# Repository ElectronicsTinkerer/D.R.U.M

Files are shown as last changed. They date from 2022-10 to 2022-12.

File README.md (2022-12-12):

# D.R.U.M (Digital Rhythmic Utility Modules)
Files for the D.R.U.M. Machine, the modular, expandable drum machine complete with digital AND analog circuitry!

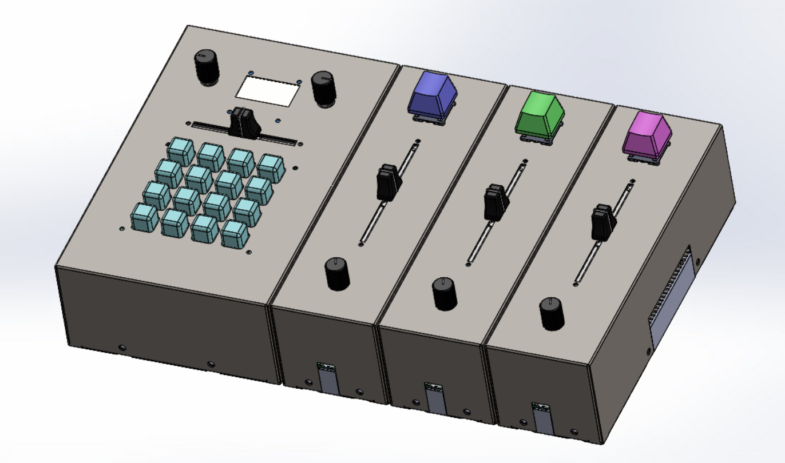
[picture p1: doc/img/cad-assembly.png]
CAD rendering of the DRUM sequencer with three modules attached to its right size

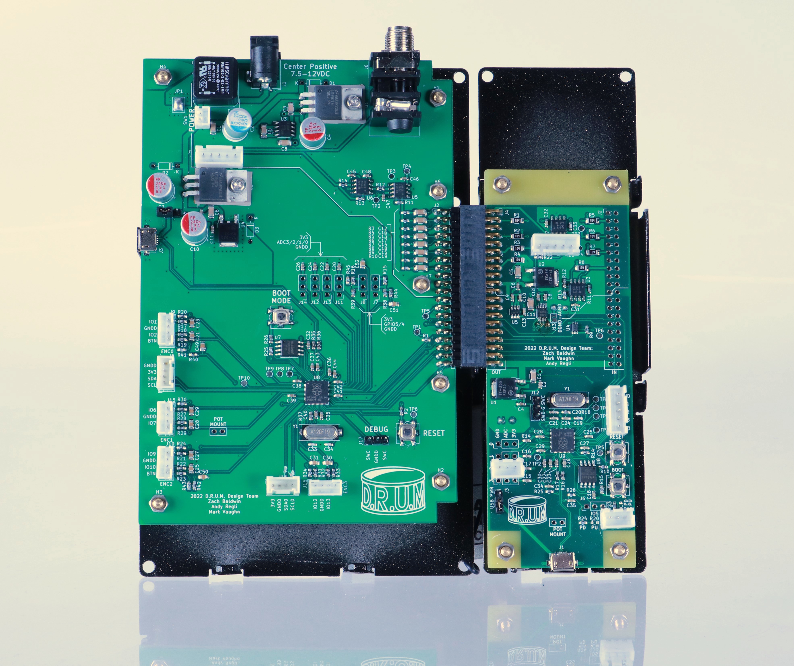
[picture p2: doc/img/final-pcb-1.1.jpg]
Assembled PCBs, mounted to the bottom of the housing

Fully assembled device

## File Structure

```
.
├── doc             # Documentation on components, thoughts, h/sware details
├── module          # Files specific to the modules
│   ├── cad         # Housing design
│   ├── hardware    # PCB design (kicad)
│   └── software    # Module firmware
├── README.md       # INFO (this doc)
├── samples         # Sample to c-array conversion utils
│   └── bass-0      # Revision 0 Bass Drum samples (RAW, PCM-16)
├── sequencer       # Files specific to the sequencer
│   ├── cad         # Housing design
│   ├── hardware    # PCB design (kicad)
│   └── software    # Sequencer firmware
└── slidepot        # Slide potentiometer daughter board
    ├── cad         # 3D models for slidepot (knob)
    └── hardware    # Daughter board design
```

## System Architecture

The D.R.U.M. system is composed of a sequencer (the base and primary controller) and between 1 and 8 "modules." The digital section of each device is based on the RP2040 microcontroller, the same device found on the Raspberry Pi Pico development board. The RP2040 was selected due to its relatively high clock speed (compared to a '328, for example), multiple cores, its PIO state machines, good documentation, and great SDK. (Oh, and it's only $1). 

The **analog section** is designed around a completely passive routing scheme, where each of the channels is simply shifted one position over each module. This allows for up to 8 modules to be connected in series before a summing module is necessary to combine the channels. Each module has a 100k pull down resistor on the lines to ensure that they are not floating. The eight lines enter the sequencer for final summation and are dc isolated via separate capacitors for each line. Although currently unused, each module also has a comparator circuit on channel 8 to detect when all the channels have been filled to signal to the RP2040 onboard that the max channel count has been reached. Each module is in charge of the amplitude that it outputs; that is, the mixing between each module is performed on a per-module basis.

The **digital section** is designed around the RP2040 microcontroller. All the modules communicate over a 32-bit SPI-like scan chain which is controlled by the sequencer. The scan chain is further documented below. The modules have the ability to send an interrupt to the sequencer when they have been "(un)selected" by the user. Only one device can be "selected" at a time. Being selected means that that module's data will be copied to the sequencer and displayed on the UI. Deselection of the module hides this information from the user but retains it within the module's memory, allowing multiple modules to have different user data. Tempo synchronization between the modules is accomplished by an interrupt line which is driven by the sequencer. This outputs a periodic pulse each "tick" (currently each beat, but in the future when microbeats are implemented, this will pulse each microbeat). The length of the tick tells the module if the beat is the start of a new measure. A short pulse (<75us) is beat 0 while a long pulse (>75us) is any other beat.

The overall routing of signals is approximated by the following diagram:

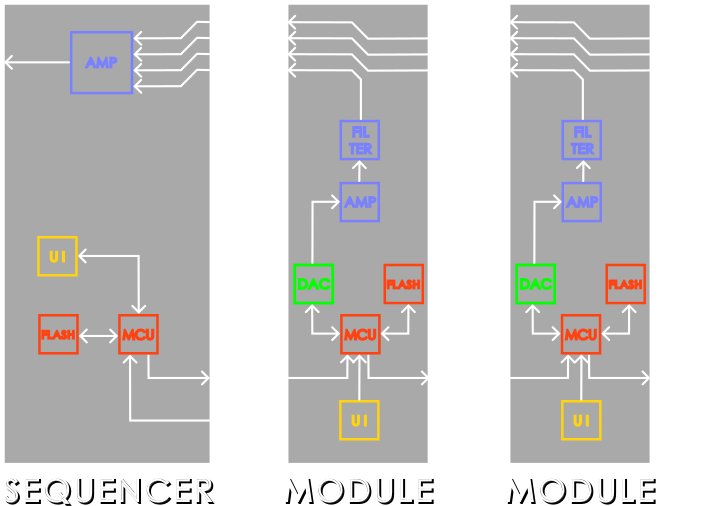
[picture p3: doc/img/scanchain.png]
System architecture block diagram


## Docs

The `doc` directory contains most of the relevant documentation to this project. This will contain information about different parts of the system, such as the serial bus protocol or the data sheets for the components used.

* [`serbus.md`](doc/serbus.md) contains information on the custom 32-bit scan chain protocol used for communication between modules. This is implemented using the RP2040's PIO state machines, meaning that the bus can be much faster than bit-banging in software. It also allows an "address-free" control scheme, where modules (bus devices) are selected by their depth on the scan chain, rather than an address. This allows a user to completely fill the bus with 8 of the same module if desired.
* [`ipc.md`](doc/ipc.md) contains information on how information is sent between the different processes running on the sequencer and the module. Both CPU cores on the RP2040 are utilized in each design to allow simultaneous execution of multiple tasks. In the case of the sequencer, the I2C bus is rather slow compared to the amount of data to be sent over it, so the second thread (core 1) handles data modification and transfer to/from the modules.
* [`samples.md`](doc/samples.md) contains information on the used sample format and how playback is achieved as well as how the signed to unsigned conversion is performed.

## Usage

### Power Up / Reset

Upon power up, the sequencer will run through an auto detection routine to determine how many modules are connected. It also will cycle all neo pixels in the 4x4 grid pad white to visually test that all LEDs and their individual colors are functioning properly. After this initialization sequence is performed, the sequencer will display its default config on the OLED screen.

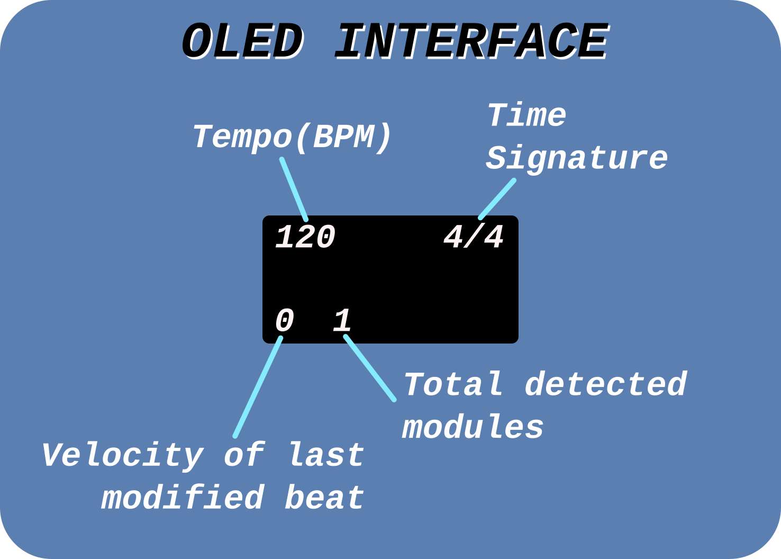
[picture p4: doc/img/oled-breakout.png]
OLED interface diagram; Tempo in upper left, time signature in upper right, last modified velocity in lower left, detected module count


### Programming a Beat

To start programming in a beat, the user must first select the module that they would like to program. Modules should have a button on board along with a visual indicator which can be used to select/deselect a module and identify if a module is selected. When a module is selected, the current contents of the sequencer's beat grid are saved to the previously selected module and the newly selected module's saved beat data is loaded into the grid.

Each square on the grid represents a sixteenth note (1/16) at the current tempo marking (although this may be changed in future revisions). Additionally, each square can have up to 7 different values associated with it. These values are called the *velocity* of that note. In addition to the 7 different velocities, a square can be off, giving 8 total possible states. The state of all the squares is indicated by the color of that square. Additionally, each time that a square is pressed, its new velocity value is displayed on the OLED screen to give quantitative feedback on any changes. Beats can be programmed while the sequencer is in active playback or while the system is in a stopped state.

### Playback

Playback is controlled by the tempo knob. This knob controls the tempo by rotating it; clockwise increases the tempo by one beat per minute per click of the knob and counter-clockwise decreases the tempo. Pressing the know will switch the sequencer between active playback, *sequencing*, and stopped, *idle*, states. During playback, the current square will light up white to indicate the location of the beat. This light will extinguish during the idle state.

The time signature of the playback can be changed via the time signature knob. This cycles through all built-in time signatures in a circular manner. Beats which are not available in a given time signature will be "grayed out" with a dim white square. Note that beats which had been programmed before changing the time signature but are not available in a new time signature will retain their original values but will not be played back. Holding down the time signature knob for about one second will clear the current pattern on the grid.

### Interface

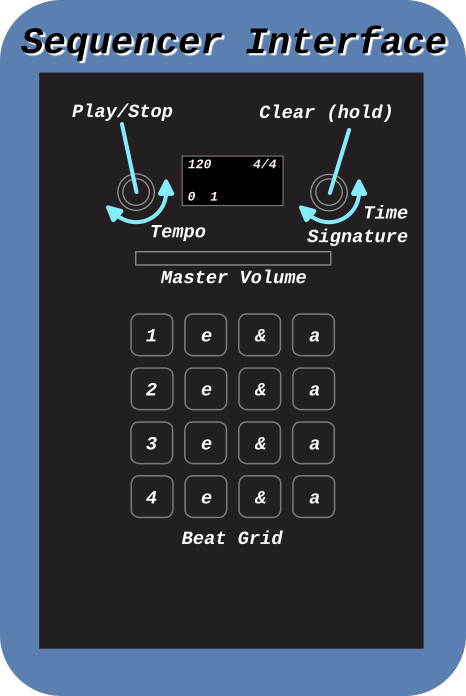
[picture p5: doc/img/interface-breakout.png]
Interface breakout of the sequencer


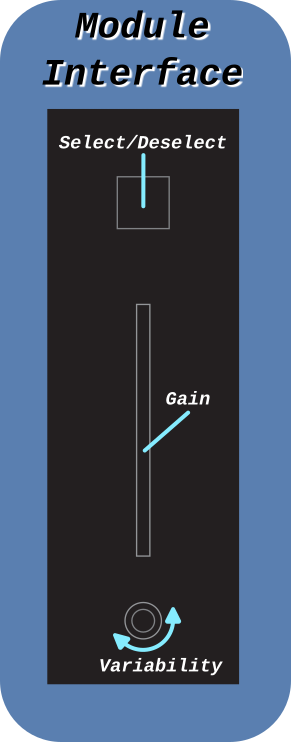
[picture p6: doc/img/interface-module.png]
Interface breakout of the bass module


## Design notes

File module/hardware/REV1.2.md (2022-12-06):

# Things to fix in module HW REV 1.2

* Incorrect GPIO numbering in silk for button inputs
* Incorrect GPIO numbering for encoder inputs

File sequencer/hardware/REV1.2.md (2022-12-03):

# Things to fix in REV 1.2

* Incorrect pinout of 40-pin header
* I2C0 needs to be common between OLED and button pad
* Rotate button footprint
* Update USB micro connector footprints (the pegs don't have holes)
* Fix silk error on debug header (incorrect pin labels)
* Move output level pot header to right side of board (near output jack)

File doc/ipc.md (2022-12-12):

# Inter-Process Communication

Communication between the processes approximately follows the following flow diagram. Note that the PIO state machines are excluded from the diagram. They are implicitly contained "within" core 1 to allow the cores to use the scan chain.

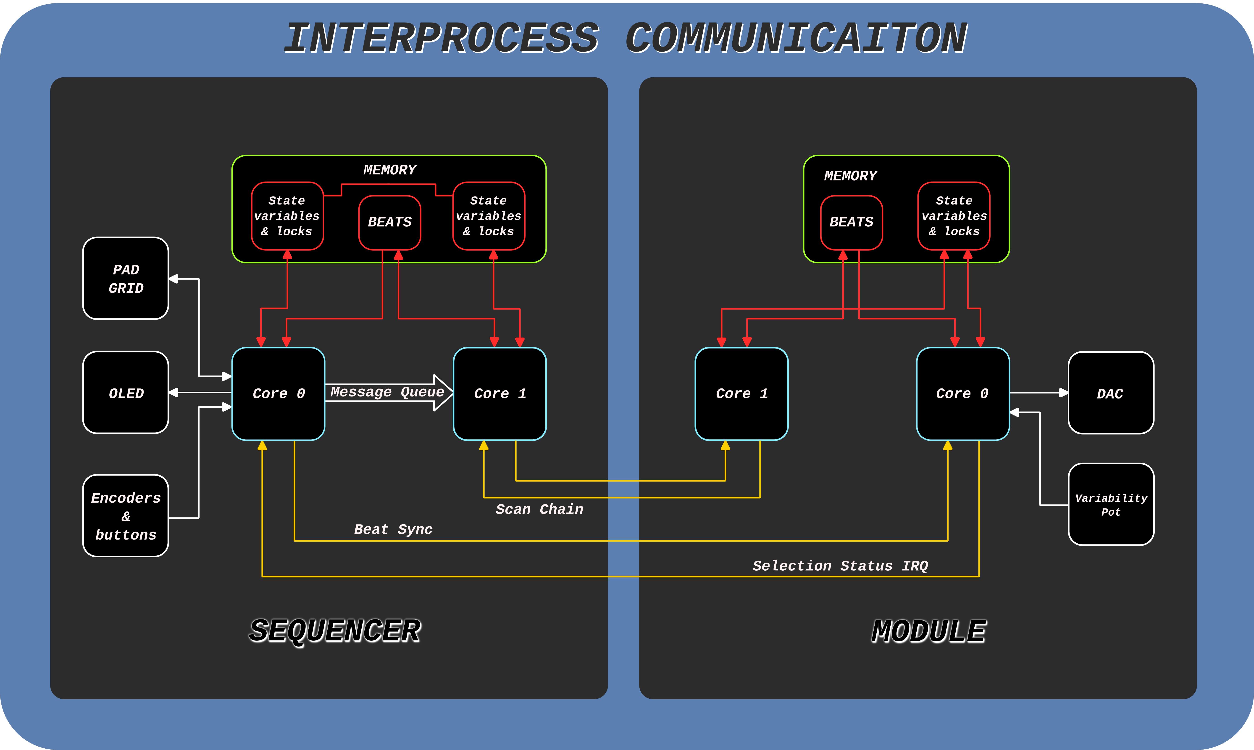
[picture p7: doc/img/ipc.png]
Inter-process communication diagram between sequencer and module


The sequencer performs most of the tasks in the system. It is in charge of performing synchronization between the modules, handling rhythm input, handling time signature adjustments, reading from and writing data to the modules, and displaying the current system state. Since the RP2040 is a dual core device, both cores are utilized to improve response time to interrupts. Core 0 handles all user interface data as well as synchronization between modules. Due to the relatively slow speed (400k BAUD) of the I2C bus that the 4x4 keypad and OLED screen are connected to, relative to the amount of data which needs to be sent to the devices, core 0 is in use for the majority of the time. To relieve core 0 of some tasks, user inputs which change parameters of the modules, such as changing the velocity of a beat or clearing the grid, are simply put into a message queue. Core 1 then reads from this message queue and updates the sequencer’s internal data structures to reflect this change. Core 0 reads these changes on the next cycle of its event loop and updates the UI to reflect them. Both cores are synchronized through the use of mutexes (mutual exclusion tokens) and critical section entrance/exit calls. These synchronization mechanisms are included in the SDK and are both multi-thread and interrupt safe.

In addition to updating the internal data structures, core 1 also is in charge of managing the intermodule scan chain. When an event is sent into the message queue, that event’s beat data is then sent to the currently selected module. Only modified beats are sent to the module since the module’s state is copied to the sequencer upon selection. Additionally, core 1 checks to make sure that the message queue is empty before allowing a new module to be selected. This prevents pending data in the queue from being sent to the wrong module. 

Beat synchronization between the sequencer and the modules is achieved by a data line which the sequencer uses to output a low pulse at the beginning of each beat. In the future when microbeats are fully supported, this pulse will occur at the beginning of each microbeat. While not an optimal solution, the duration of the pulse is used to distinguish the beat number. A short pulse (<75us) is beat 0 while a long pulse (>75us) is any other beat on the grid. This pulse is implemented using a timer interrupt and software callback. The free running timer which generates the microbeat interrupt on core 0 contains a small section of code to detect the beginning of a beat. If the beat starts during that interrupt service routine (ISR) execution, then the synchronization line is pulled low and an alarm callback is started. The timeout of the call back is set to 25us for beat 0 and 125 us for any other beat. This gives a 50us margin on either side of the threshold for long or short beats, allowing for some delay in processing the alarm interrupt. The alarm callback restores the synchronization line to a high state. Alarms are implemented using the SDK provided functions.

The module has an interrupt registered to the pin to which the synchronization line is connected. On the falling edge, an ISR registers an alarm for 75us. When the alarm is triggered, the callback increments the beat number if the synchronization line is still low. If high, then the beat number is reset back to 0. Additionally, the callback also updates several playback variables including the beat which is currently being played back. If the new beat does not contain a note to play, the previous beat is allowed to continue playing, allowing notes to fully ring out.

When the user presses the module select button, an ISR on the module outputs a >100us negative pulse on the “open drain” line which acts as the module selection status interrupt input to the sequencer. The pulse is terminated via an alarm callback which releases the line. Since the RP2040 does not provide SDK functions to control the GPIO pins in an open drain mode, the pin is set as an input to allow the line to be pulled back high via a pull up resistor in the sequencer. To pull the line low, a logic 0 is written to the pin then the direction is switched to an output.

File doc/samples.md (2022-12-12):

# Samples and Sample Playback

Playback of beats is accomplished by synchronizing the DAC with a 44100Hz timer interrupt. The ISR for this timer pulses the /LDAC line low for about 80ns. This causes the DAC to move the value currently in the shift register to the output conversion register. The ISR also sets a synchronization variable which tells the main event loop to shift out the next sample point of the waveform currently in playback. As mentioned below, the samples are recorded as a 16-bit signed number but the DAC uses an unsigned 16 bit number. As a result, initial sample playback resulted in a very strange waveform, as shown in the first image. The solution to this was to invert the sign of the number by adding 0x8000 to sample during playback.

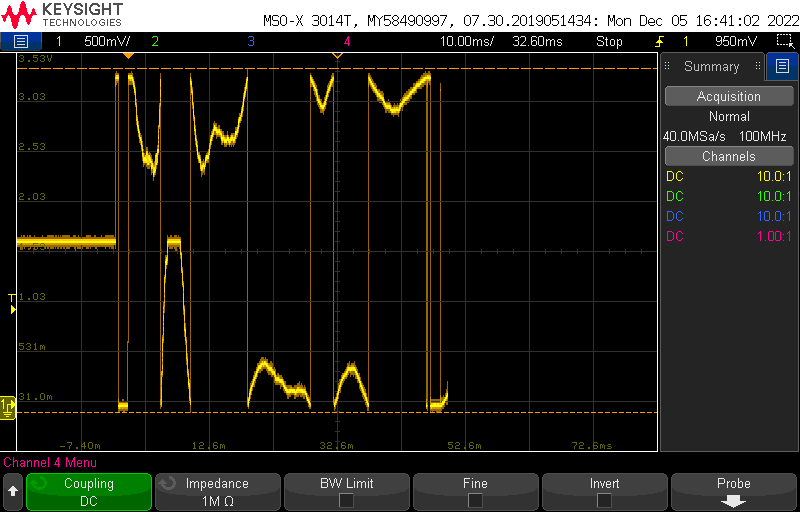
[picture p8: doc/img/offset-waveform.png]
Incorrect waveform playback due to signed offset of sample data


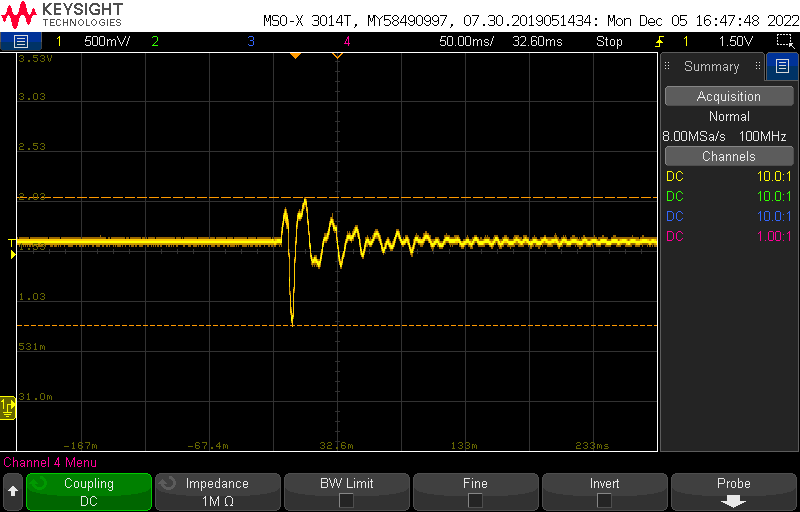
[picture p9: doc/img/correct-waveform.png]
Corrected single sample playback waveform


The samples to be played back are stored in the off chip flash IC. At each velocity of hit, there are four different recorded samples, which allows the device to implement some variation of the sound. In total, there are 32 available samples which can be played back (although the current implementation only allows the highest 7 velocities to be played, for a total of 28 samples). These are arranged into a 2D array, where the first index is the sample and the second index is the data sample to read.

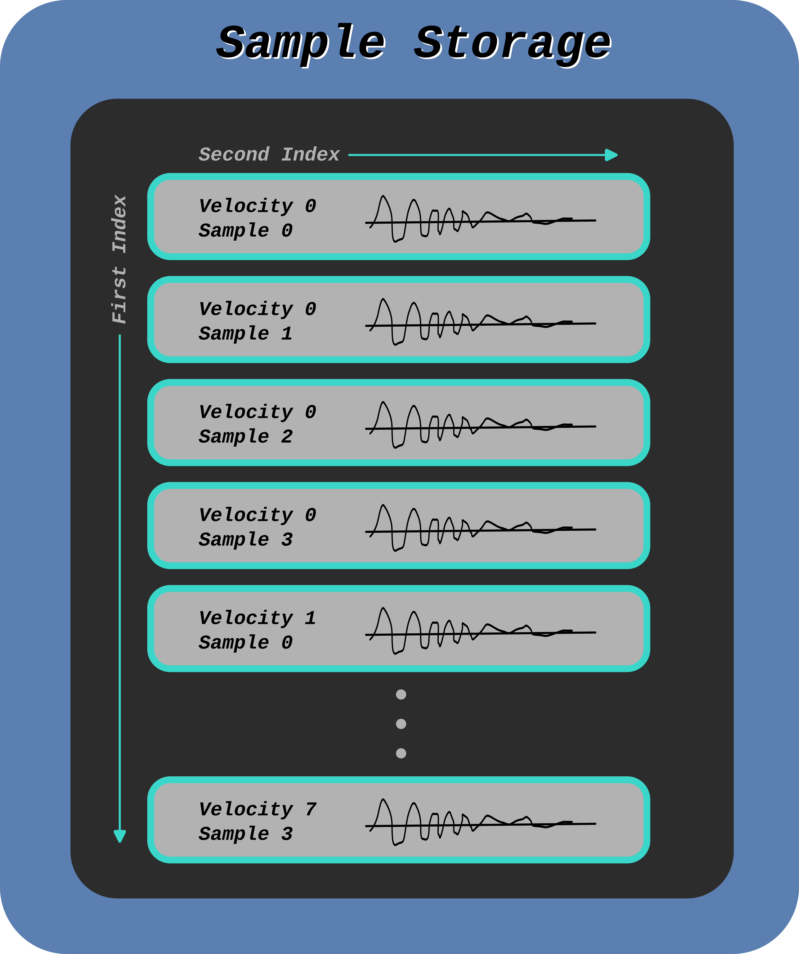
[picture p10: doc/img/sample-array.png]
Arrangement of samples in flash storage


After the samples were recorded, the freely available software, Audacity, was used to convert the recordings into headerless (RAW) 16-bit signed PCM files. Each of these files was trimmed to contain the same number of samples to allow them to be easily put into the array. A python script was written to read in these files and generate the array of data which can be included as a header file in C++. In the future, the sign adjustment mentioned earlier could be performed in the python script instead of on the fly, saving a few clock cycles.

Finally, the module includes a “debug” mode which can be entered by holding down the select button during a system reset. This causes the module to output a full scale 1kHz sine wave for rudimentary signal to noise ratio and output level testing. When the button is released, the system returns to normal operation.

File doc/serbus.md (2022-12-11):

# Inter-module Serial Bus Protocol

The bus is based on a 32-bit word size. It uses three signals, much like SPI:
* `SCK` - The clock to synchronize data transfers. This only runs during transmission of data and data is sampled during the high phase of the clock.
* `DRDY` - The Data Ready is used to signal that a shift operation has completed. This signal is low during the shift and goes high during the last high clock phase of the shift. Any devices on the scan chain should not read data into their input buffers until this goes high (but they should continue to shift data through the scan chain while DRDY is low).
* `SDxx` - The Serial Data [in/out] carries the data to be transmitted, LSb first (right shift). The data out from the master changes during the low period of the clock (ideally, on the falling clock edge). Data out from bus devices also changes at or shortly after the falling edge of the clock.

## Timing

Here's the timing diagram. Note that any multiple of 32 bits can be shifted before releasing the DRDY line. This allows data to be shifted any arbitrary distance into the scan chain before the modules read and execute that word.

Timing diagram of the inter-module serial protocol

## Scan Chain

The scan chain is fairly straight forward. The sequencer is the 'master' of the bus and is what controls all shift operations. 

Picture showing the scanchain routing from the sequencer, through the modules, and back to the sequencer.

## Frame Format

The data frames are independent of the protocol for the most part, except that CS and RWB bits should always be kept as the upper two most significant bits of the word, respectively. For the DRUM modules, the word follows the following frame format:

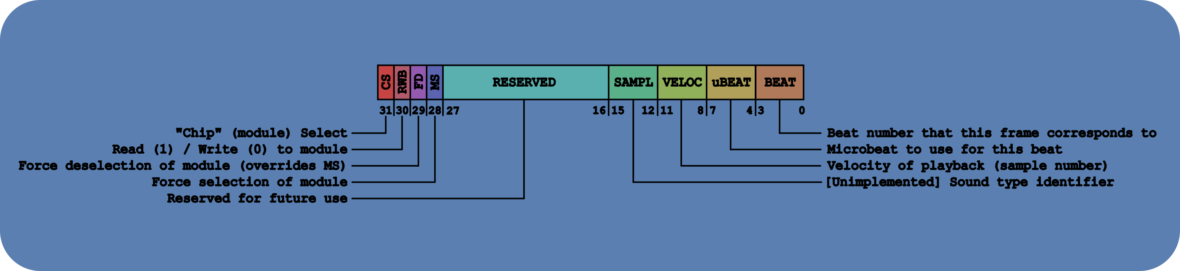
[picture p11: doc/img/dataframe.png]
Frame format for the inter-module communication bus which is used by the DRUM system.


More details:

* **CS** "Chip select" is 1 when the master wants the bus device to execute the command that is shifted in when DRDY goes high. It is 0 otherwise.
* **RWB** "Read/Write" is 1 when the master wants to perform a read operation. It is 0 to perform a write.
* **FD** "Force Deselection" is 1 when the master wants to force the bus device to deselect itself. No effect if 0. Note that this overrides the *MS* bit if *FD* is set to 1. Also, if *FD* is set to 1, data in any field which is not *CS*, *RWB*, or *FD* is ignored.
* **MS** "Module Select" Force selection of the bus device (module) if set to 1. No effect if 0. If *MS* is set to 1, data in any field which is not *CS*, *RWB*, *FD*, or *MS* is ignored.

## Data Transfer

### Write Operation

To perform a write operation to one or more modules, the master will set *CS*=1, *RWB*=0, and the other data fields as needed to carry the appropiate data. This can be done for as many bus devices as there are in the scan chain.

### Read Operation

To perform a read operation to one or more modules, the master will set *CS*=1, *RWB*=1, and the other data fields as needed to carry the appropriate data. The master first sends out a command word to the bus device(s) that it wants to read from. It then raises DRDY (as it would for a write operation). Since the v1.0 protocol does not make use of handshaking, the master must wait some time (currently, 100us) before performing another shift operation through the scan chain to shift the results of the read operation back into the master's RX buffer. During the wait period between command and read shifts, the bus device must execute the command and replace the contents of its shift register with the result of the read operation.

## Device Discovery

The sequencer needs a method to determine the number of devices currently connected on the scan chain. Since the maximum length of the chain is set to be eight modules (determined by the analog routing scheme), the sequencer shifts out eight command words which are zeroed to clear the scan chain. It ignores any data shifted back in during this operation. Following the clear operation, the sequencer then sends out a magic number command which is designed so that it does not trigger an operation on the modules (CS=0). It then repeatedly shifts out this command word until it receives it in its Rx shift register. If it does not find this word within eight shifts, it defaults to the condition that no modules are connected.

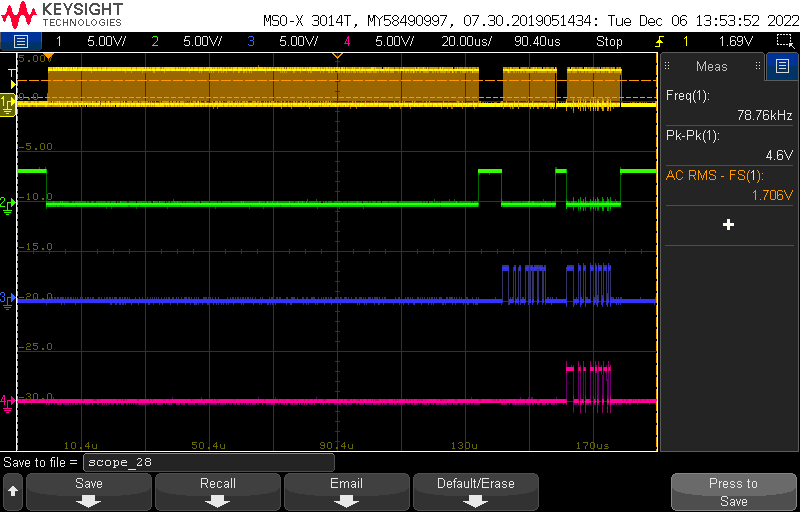
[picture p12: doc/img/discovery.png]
Oscillscope capture of serial bus performing a scan of the chain with one device attached


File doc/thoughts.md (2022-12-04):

# Random things that might be good to think about in the future

* Add some form of handshaking between the module and sequencer for read operations
* Reverse the direction of the scan chain so that module is the leftmost (closest to the sequencer) instead of the rightmost.

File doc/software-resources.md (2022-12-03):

# Software Resources

Online places for documentation

[Pi Pico C/C++ SDK](https://raspberrypi.github.io/pico-sdk-doxygen/index.html)
* [Queues](https://raspberrypi.github.io/pico-sdk-doxygen/group__queue.html)
* [Mutexes](https://raspberrypi.github.io/pico-sdk-doxygen/group__mutex.html)
* [Critical Sections & Spin Locks](https://raspberrypi.github.io/pico-sdk-doxygen/group__critical__section.html)

[Multiple interrupts on RP2040 in C](https://forums.raspberrypi.com/viewtopic.php?t=314186)

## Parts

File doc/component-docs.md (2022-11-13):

# Datasheets and Documents

This file contains any relevant links to guides, datasheets, or application notes that may be helpful for the components used in the D.R.U.M project.

## RP2040 (MCU)
* [Datasheet](https://datasheets.raspberrypi.com/rp2040/rp2040-datasheet.pdf)
* [C/C++ SDK setup](https://www.raspberrypi.com/documentation/microcontrollers/c_sdk.html#sdk-setup)
* [Getting Started PDF](https://datasheets.raspberrypi.com/pico/getting-started-with-pico.pdf)
* [Design Reference](https://datasheets.raspberrypi.com/rp2040/hardware-design-with-rp2040.pdf)

## W25Q128JVSIM (QSPI FLASH)
* [Datasheet](https://www.winbond.com/resource-files/w25q128jv_dtr%20revc%2003272018%20plus.pdf)

## MAX5206 (DAC)
* [Datasheet](https://datasheets.maximintegrated.com/en/ds/MAX5204-MAX5207.pdf)

## 74LVC2G53 (2x1 MUX)
* [Datasheet](https://www.ti.com/lit/ds/symlink/sn74lvc2g53.pdf)

## OPA340 (OP-AMP)
* [Datasheet](https://rocelec.widen.net/view/pdf/oeyhv4mosm/sbos073c.pdf)

## MAX6070AAUT33 (Voltage Reference)
* [Datasheet](https://www.digikey.com/en/products/detail/analog-devices-inc-maxim-integrated/MAX6070AAUT33-T/4156352)

## PTA45/6043 (Slide Potentiometers)
* [Datasheet](https://www.bourns.com/docs/Product-Datasheets/pta.pdf)

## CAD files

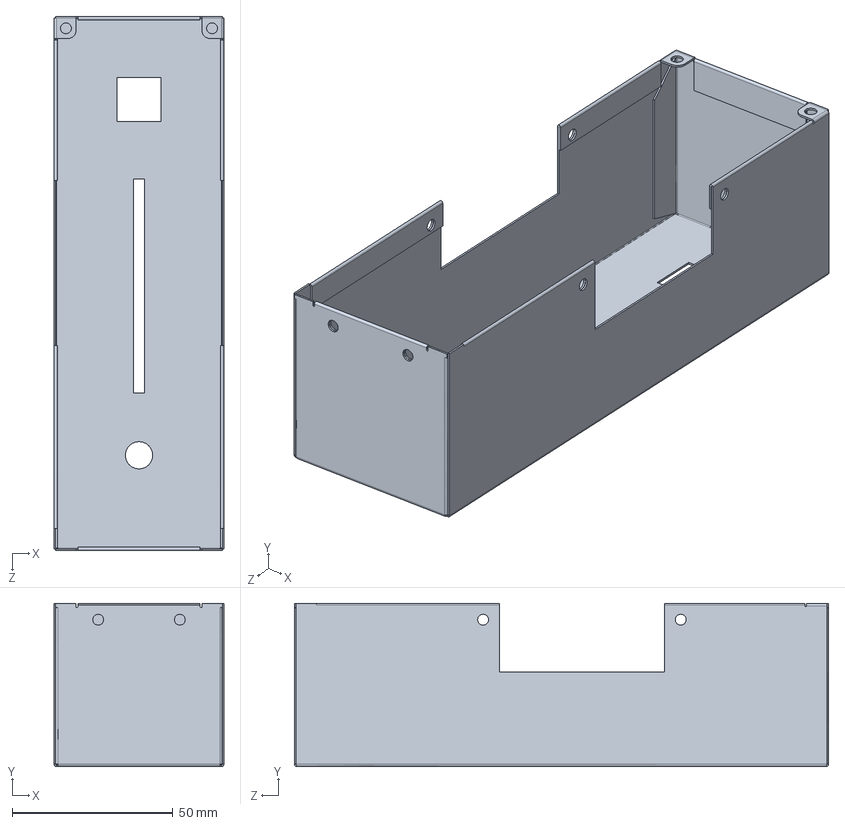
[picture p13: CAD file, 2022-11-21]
module/cad/MainEnclosure.SLDPRT
52.9 x 50.8 x 166.2 mm

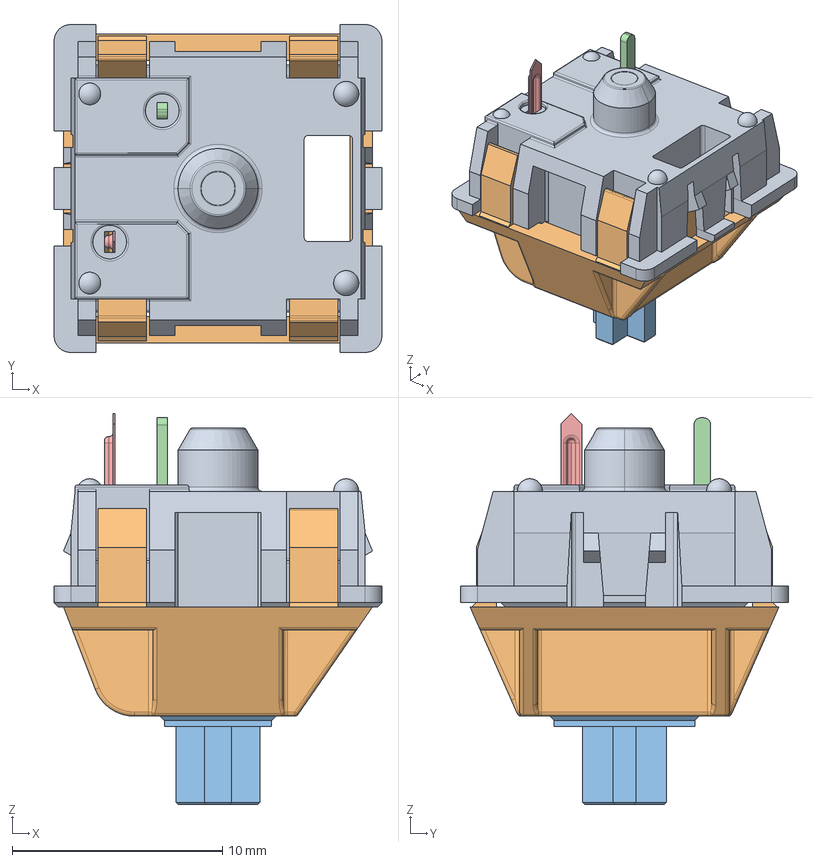
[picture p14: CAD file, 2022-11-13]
module/cad/asm_mx_asm_PLATE.stp
15.6 x 15.6 x 18.6 mm
MX_DOWN
MX_UP
UP_MX
MX_PIN
MX_SPRING
MX_CLICK

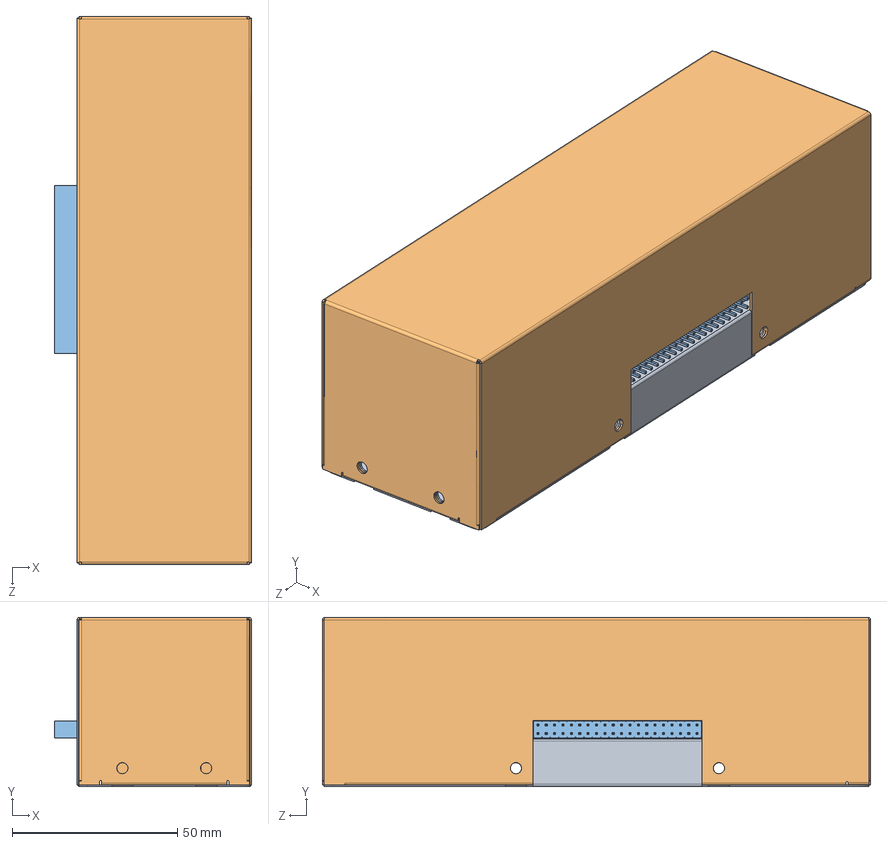
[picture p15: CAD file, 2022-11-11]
module/cad/moduleAssem.SLDASM
59.7 x 51.3 x 166.2 mm
BasePlate
MainEnclosure
module-hardware.step

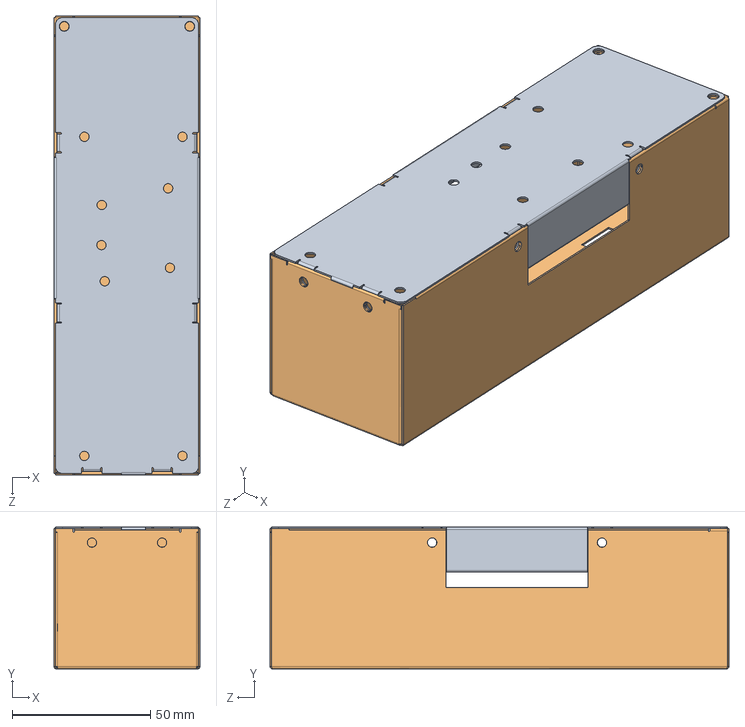
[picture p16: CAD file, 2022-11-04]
sequencer/cad/EnclosureAssembly.SLDASM
52.9 x 51.3 x 166.2 mm
MainEnclosure
BasePlate

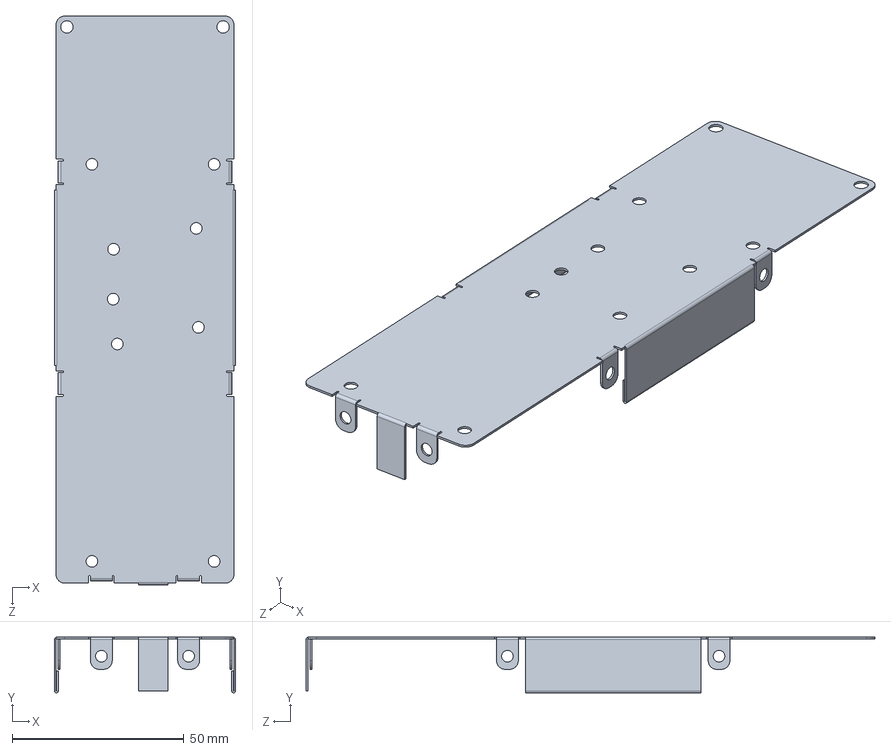
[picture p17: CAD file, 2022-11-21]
module/cad/BasePlate.SLDPRT
52.7 x 16.3 x 165.6 mm

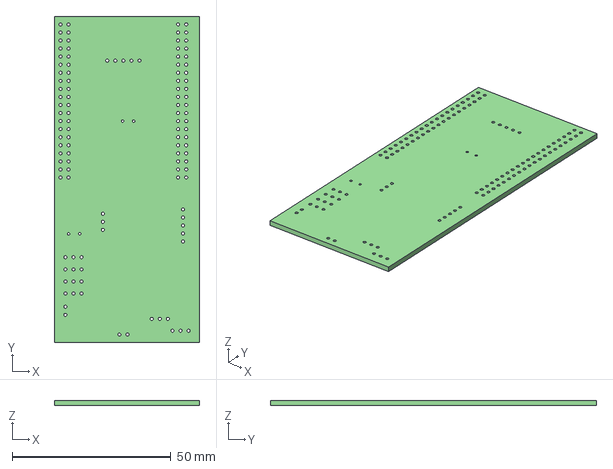
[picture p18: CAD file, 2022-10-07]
module/hardware/module-hardware.step
45.7 x 102.9 x 1.60 mm

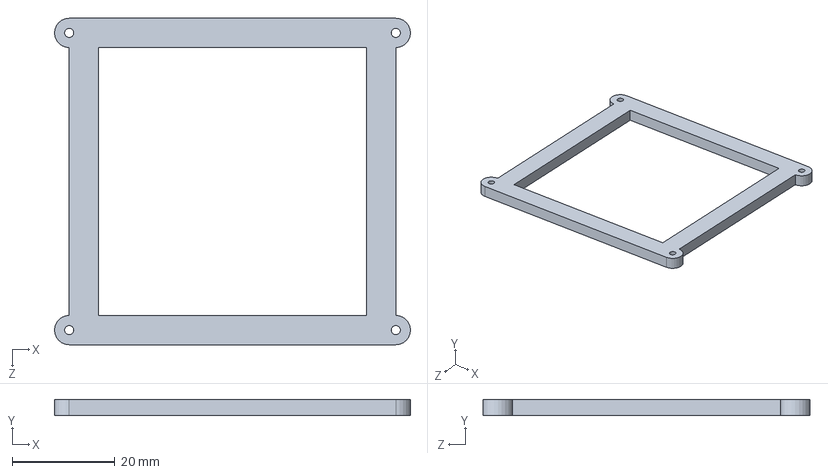
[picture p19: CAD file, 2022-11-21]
sequencer/cad/KeypadSandwich.SLDPRT
69.2 x 3.17 x 63.5 mm

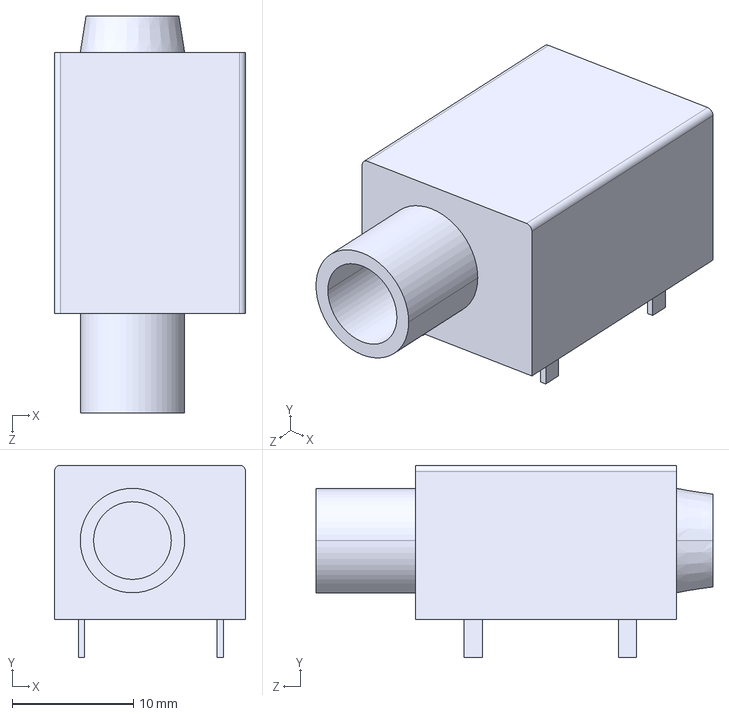
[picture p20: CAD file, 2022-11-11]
sequencer/hardware/TS.STEP
15.8 x 15.8 x 32.7 mm

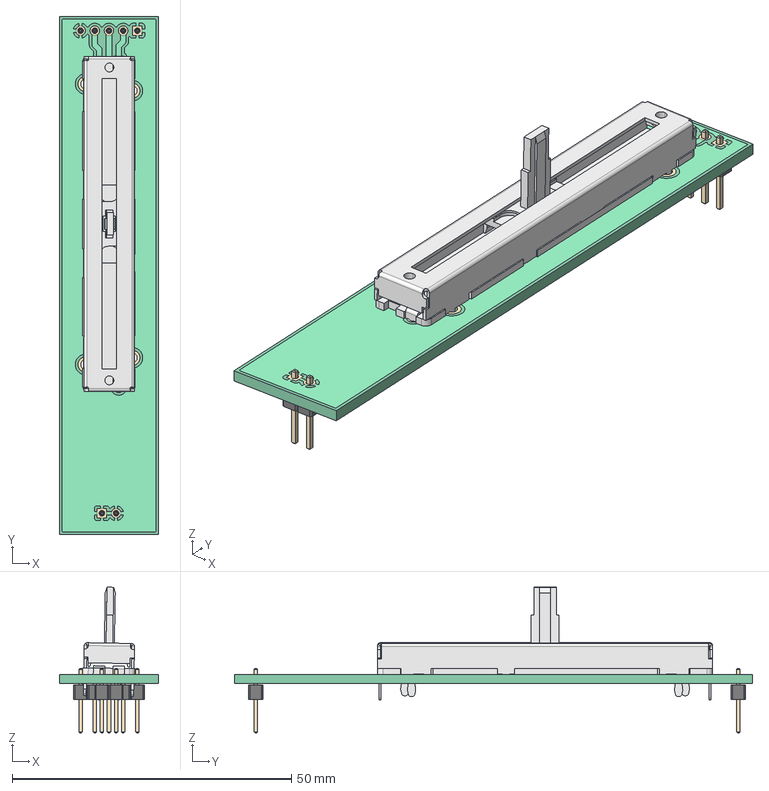
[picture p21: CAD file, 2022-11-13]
slidepot/cad/slidepot-45/slidepot-45.step
17.8 x 92.7 x 26.1 mm
Local_CS_c79d
Pcb_c79d
PCB_Sketch_c79d
topPads_c79d
topTracks_c79d
topZones_c79d
botPads_c79d
botZones_c79d
J1_PinHeader_1x05_P254mm_Vertical_af7242d1aa5f
J2_PinHeader_1x02_P254mm_Vertical_ff61df4ceab8

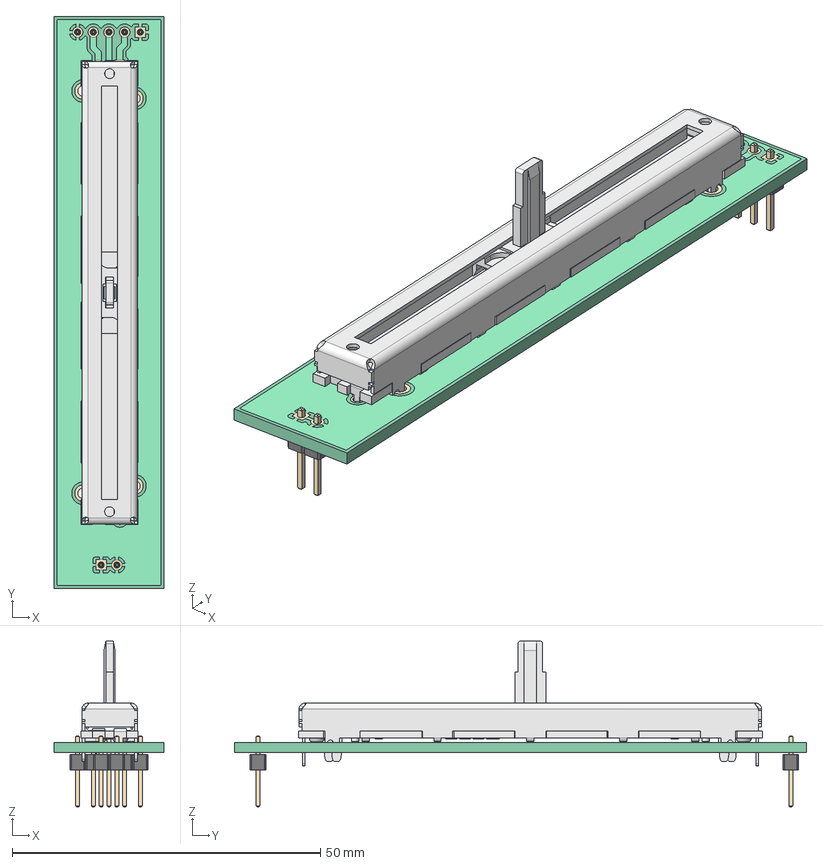
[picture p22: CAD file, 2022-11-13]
slidepot/cad/slidepot-60/slidepot-60.step
17.8 x 92.7 x 26.9 mm
Local_CS_f15a
Pcb_f15a
PCB_Sketch_f15a
topPads_f15a
topTracks_f15a
topZones_f15a
botPads_f15a
botZones_f15a
J1_PinHeader_1x05_P254mm_Vertical_af7242d1aa5f
J2_PinHeader_1x02_P254mm_Vertical_ff61df4ceab8

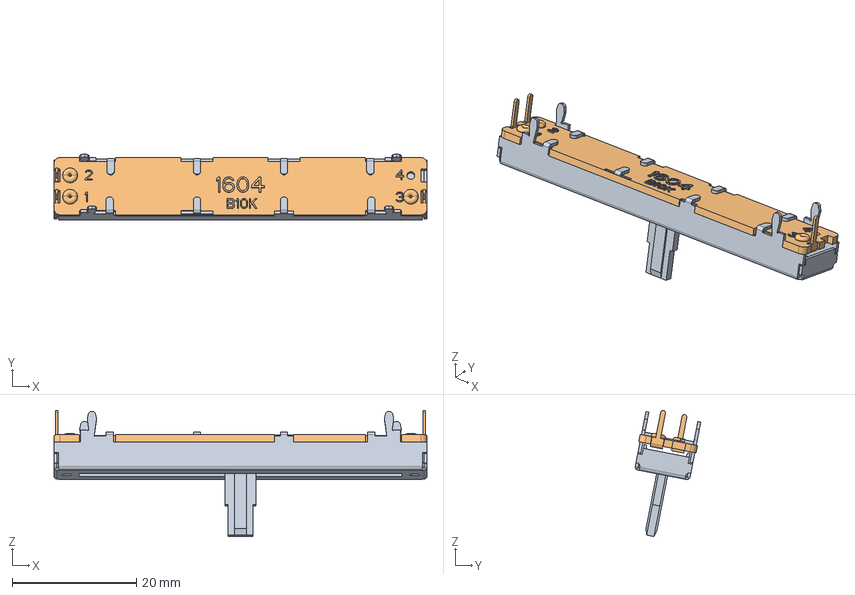
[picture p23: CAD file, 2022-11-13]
slidepot/hardware/slidepot-45s/PTA4543.stp
60.0 x 10.6 x 20.3 mm

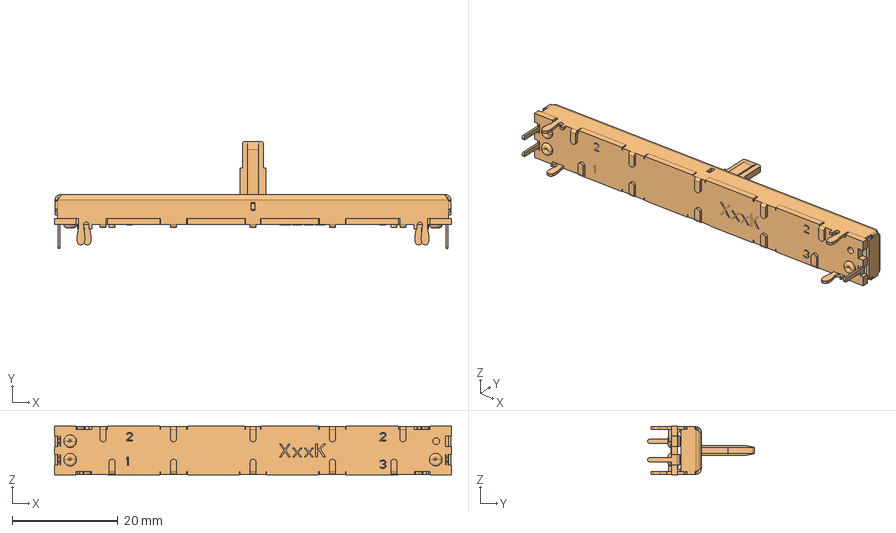
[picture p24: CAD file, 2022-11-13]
slidepot/hardware/slidepot-60/pta6043-2x10cixxxx.stp
75.2 x 20.2 x 9.20 mm

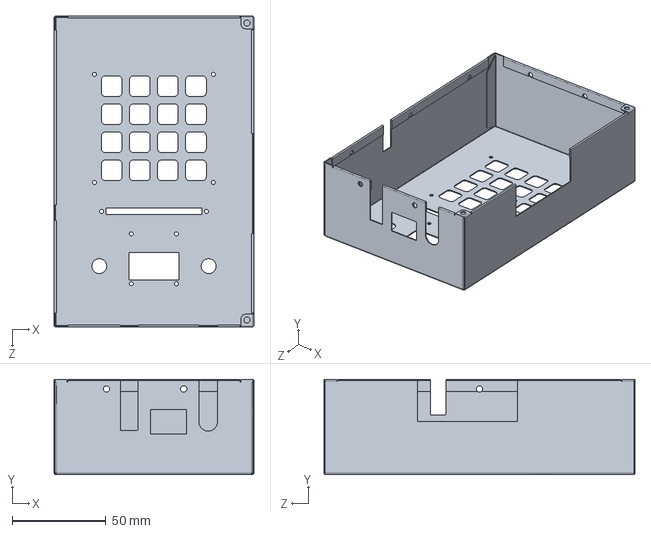
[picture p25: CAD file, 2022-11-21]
sequencer/cad/SeqTop.SLDPRT
106.7 x 50.8 x 166.2 mm

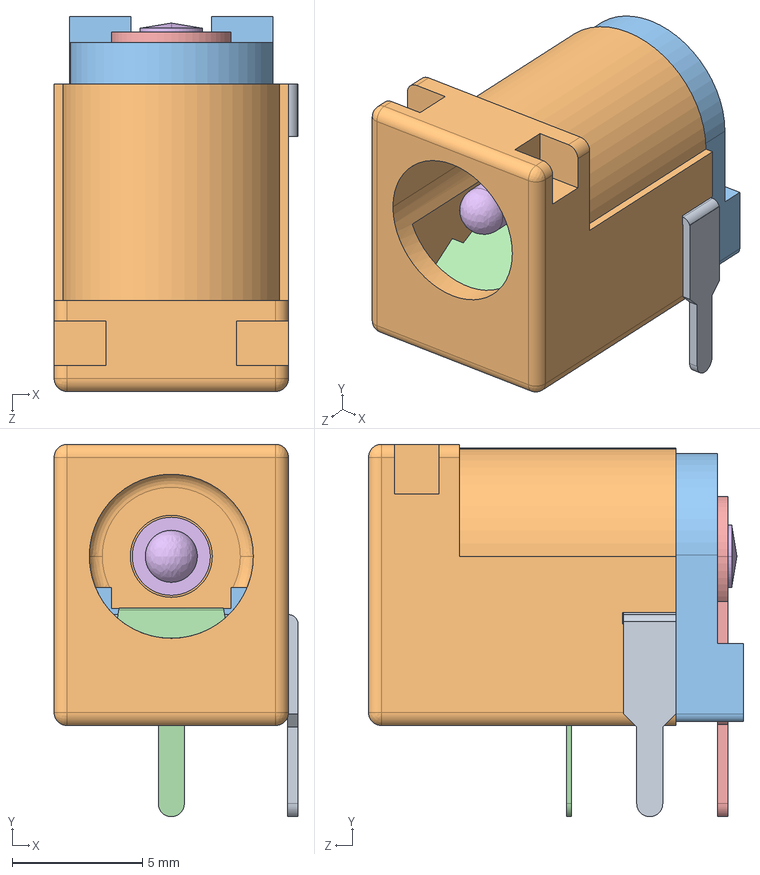
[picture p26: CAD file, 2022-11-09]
sequencer/hardware/54-00133.STEP
9.36 x 14.3 x 14.4 mm

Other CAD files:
module/cad/asm_mx_asm_PLATE.stp.SLDPRT
slidepot/cad/slidepot-45/slidepot-45.step.SLDPRT
slidepot/cad/slidepot-60/slidepot-60.step.SLDPRT
module/cad/SIFAM - Slider Cap (black) .stp
module/cad/RV24AF-22-15K.step
sequencer/cad/Adafruit 0.96in 128x64 OLED STEMMA QT.step
sequencer/cad/Adafruit 0.96in 128x64 OLED STEMMA QT.step.SLDPRT
sequencer/cad/Adafruit Trellis 3mm.stp
sequencer/cad/Black - With Line (D-Shaft).stp
sequencer/cad/RotaryEncoder.STEP
sequencer/cad/SIFAM - Slider Cap (black) .stp
sequencer/cad/SeqBase.SLDPRT
sequencer/cad/TSJack.SLDPRT
sequencer/cad/seqPCB.step

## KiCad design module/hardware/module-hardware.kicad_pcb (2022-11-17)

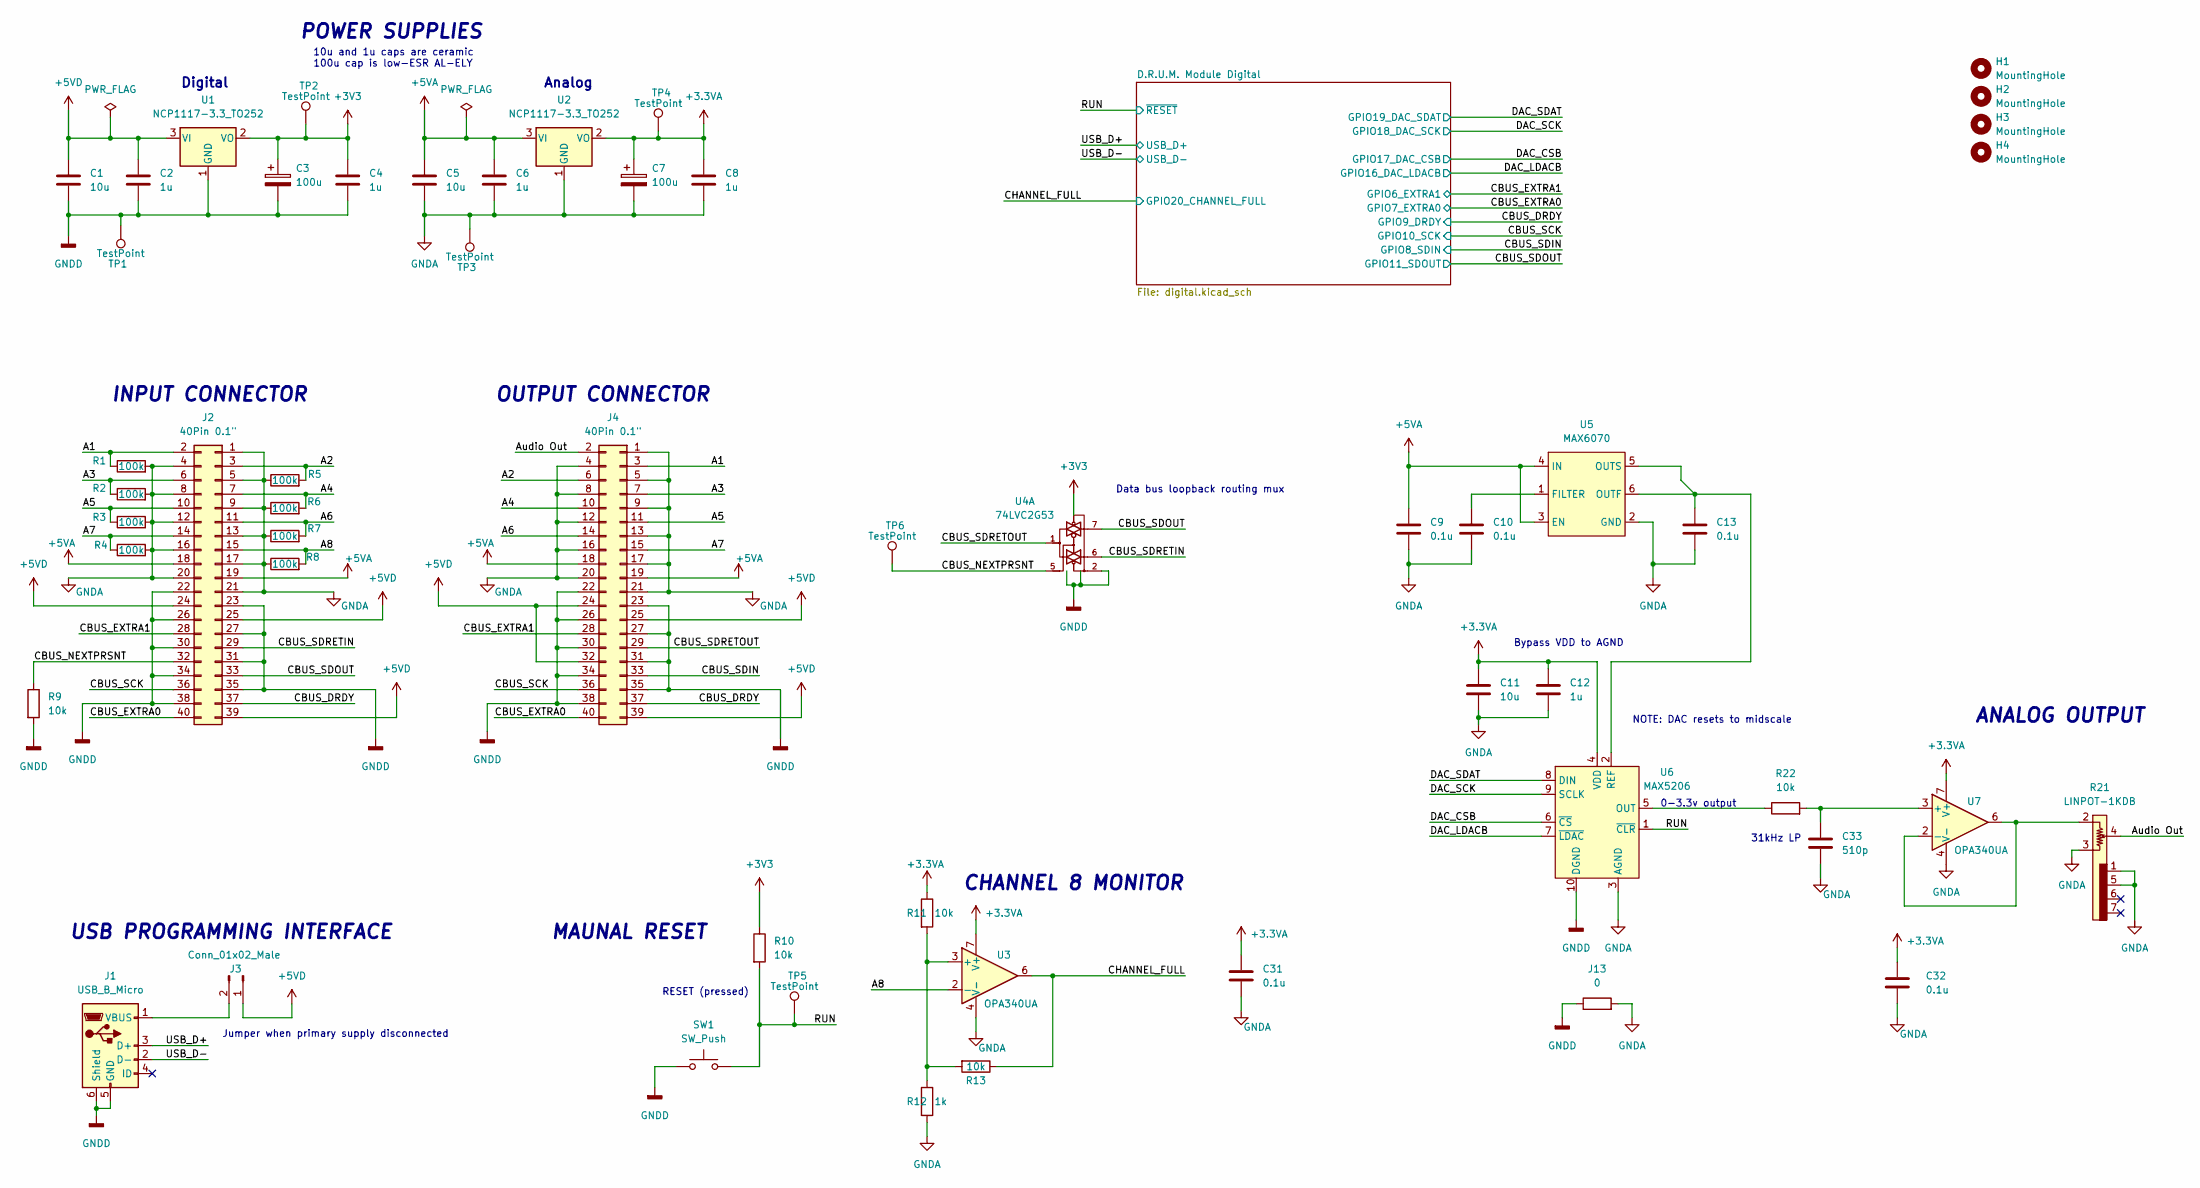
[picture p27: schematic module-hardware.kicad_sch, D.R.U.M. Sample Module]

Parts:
C1, C5, C11: 10u; C_1206_3216Metric_Pad1.33x1.80mm_HandSolder
C2, C4, C6, C8, C12: 1u; C_0603_1608Metric_Pad1.08x0.95mm_HandSolder
C3, C7: 100u; CP_Radial_D8.0mm_P3.50mm
C9, C10, C13, C31, C32: 0.1u; C_0603_1608Metric_Pad1.08x0.95mm_HandSolder
C33: 510p; C_0603_1608Metric_Pad1.08x0.95mm_HandSolder
H1, H2, H3, H4: MountingHole; MountingHole_3.2mm_M3
J1: USB_B_Micro; USB_Micro-B_Amphenol_10104110_Horizontal
J2: 40Pin 0.1"; PinHeader_2x20_P2.54mm_Horizontal
J3: Conn_01x02_Male; PinHeader_1x02_P2.54mm_Vertical
J4: 40Pin 0.1"; PinSocket_2x20_P2.54mm_Horizontal
J13: 0; SolderJumper-2_P1.3mm_Open_TrianglePad1.0x1.5mm
R1, R2, R3, R4, R5, R6, R7, R8: 100k; R_1206_3216Metric_Pad1.30x1.75mm_HandSolder
R9, R10, R11, R13, R22: 10k; R_0603_1608Metric_Pad0.98x0.95mm_HandSolder
R12: 1k; R_0603_1608Metric_Pad0.98x0.95mm_HandSolder
R21: LINPOT-1KDB; LINPOT-10KDB
SW1: SW_Push; TE_ConnMSLPT5252CG1
TP1, TP2, TP3, TP4, TP5, TP6: TestPoint; TestPoint_Pad_D1.5mm
U1, U2: NCP1117-3.3_TO252; TO-252-2
U3, U7: OPA340UA; SOIC-8_3.9x4.9mm_P1.27mm
U4: 74LVC2G53; VSSOP-8_2.3x2mm_P0.5mm
U5: MAX6070; SOT-23-6_Handsoldering
U6: MAX5206; MSOP-10_3x3mm_P0.5mm

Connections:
+3.3VA: C7.1, C8.1, C11.1, C12.1, C31.1, C32.1, R11.1, TP4.1, U2.2 (VO), U3.7 (V+), U6.4 (VDD), U7.7 (V+)
+3V3: C3.1, C4.1, R10.1, TP2.1, U1.2 (VO), U4.8 (VCC); also elsewhere on the board
+5VA: C5.1, C6.1, C9.1, J2.18, J2.19, J4.18, J4.19, U2.3 (VI), U5.3 (EN), U5.4 (IN)
+5VD: C1.1, C2.1, J2.24, J2.25, J2.39, J3.1, J4.24, J4.25, J4.32, J4.39, U1.3 (VI)
/A1: J2.2, J4.3, R1.1
/A2: J2.3, J4.6, R5.2
/A3: J2.6, J4.7, R2.1
/A4: J2.7, J4.10, R6.2
/A5: J2.10, J4.11, R3.1
/A6: J2.11, J4.14, R7.2
/A7: J2.14, J4.15, R4.1
/A8: J2.15, R8.2, U3.2 (-)
/Audio Out: J4.2, R21.4
/CBUS_DRDY: J2.37, J4.37; also elsewhere on the board
/CBUS_EXTRA0: J2.40, J4.40; also elsewhere on the board
/CBUS_EXTRA1: J2.28, J4.28; also elsewhere on the board
/CBUS_NEXTPRSNT: J2.32, R9.1, TP6.1, U4.5
/CBUS_SCK: J2.36, J4.36; also elsewhere on the board
/CBUS_SDIN: J4.33; also elsewhere on the board
/CBUS_SDOUT: J2.33, U4.7; also elsewhere on the board
/CBUS_SDRETIN: J2.29, U4.6
/CBUS_SDRETOUT: J4.29, U4.1
/CHANNEL_FULL: R13.1, U3.6; also elsewhere on the board
/DAC_CSB: U6.6 (~CS); also elsewhere on the board
/DAC_LDACB: U6.7 (~LDAC); also elsewhere on the board
/DAC_SCK: U6.9 (SCLK); also elsewhere on the board
/DAC_SDAT: U6.8 (DIN); also elsewhere on the board
/RUN: R10.2, SW1.2, TP5.1, U6.1 (~CLR); also elsewhere on the board
/USB_D+: J1.3 (D+); also elsewhere on the board
/USB_D-: J1.2 (D-); also elsewhere on the board
GND: C1.2, C2.2, C3.2, C4.2, J1.5 (GND), J1.6 (Shield), J2.22, J2.23, J2.26, J2.27, J2.30, J2.31, J2.34, J2.35, J2.38, J4.22, J4.23, J4.26, J4.27, J4.30, J4.31, J4.34, J4.35, J4.38, J13.1, R9.2, SW1.1, TP1.1, U1.1 (GND), U4.2, U4.3 (GND), U4.4 (GND), U6.10 (DGND); also elsewhere on the board
GNDA: C5.2, C6.2, C7.2, C8.2, C9.2, C10.2, C11.2, C12.2, C13.2, C31.2, C32.2, C33.2, J2.1, J2.4, J2.5, J2.8, J2.9, J2.12, J2.13, J2.16, J2.17, J2.20, J2.21, J4.1, J4.4, J4.5, J4.8, J4.9, J4.12, J4.13, J4.16, J4.17, J4.20, J4.21, J13.2, R1.2, R2.2, R3.2, R4.2, R5.1, R6.1, R7.1, R8.1, R12.2, R21.1, R21.3, R21.5, TP3.1, U2.1 (GND), U3.4 (V-), U5.2 (GND), U6.3 (AGND), U7.4 (V-)
unnamed: C10.1, U5.1 (FILTER)
unnamed: C13.1, U5.5 (OUTS), U5.6 (OUTF), U6.2 (REF)
unnamed: C33.1, R22.2, U7.3 (+)
unnamed: J1.1 (VBUS), J3.2
unnamed: R11.2, R12.1, R13.2, U3.3 (+)
unnamed: R21.2, U7.2 (-), U7.6
unnamed: R22.1, U6.5 (OUT)

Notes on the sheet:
USB PROGRAMMING INTERFACE
Analog
ANALOG OUTPUT
10u and 1u caps are ceramic 100u cap is low-ESR AL-ELY
Data bus loopback routing mux
Jumper when primary supply disconnected
MAUNAL RESET
CHANNEL 8 MONITOR
0-3.3v output
POWER SUPPLIES
Bypass VDD to AGND
NOTE: DAC resets to midscale
RESET (pressed)
INPUT CONNECTOR
OUTPUT CONNECTOR
31kHz LP
Digital

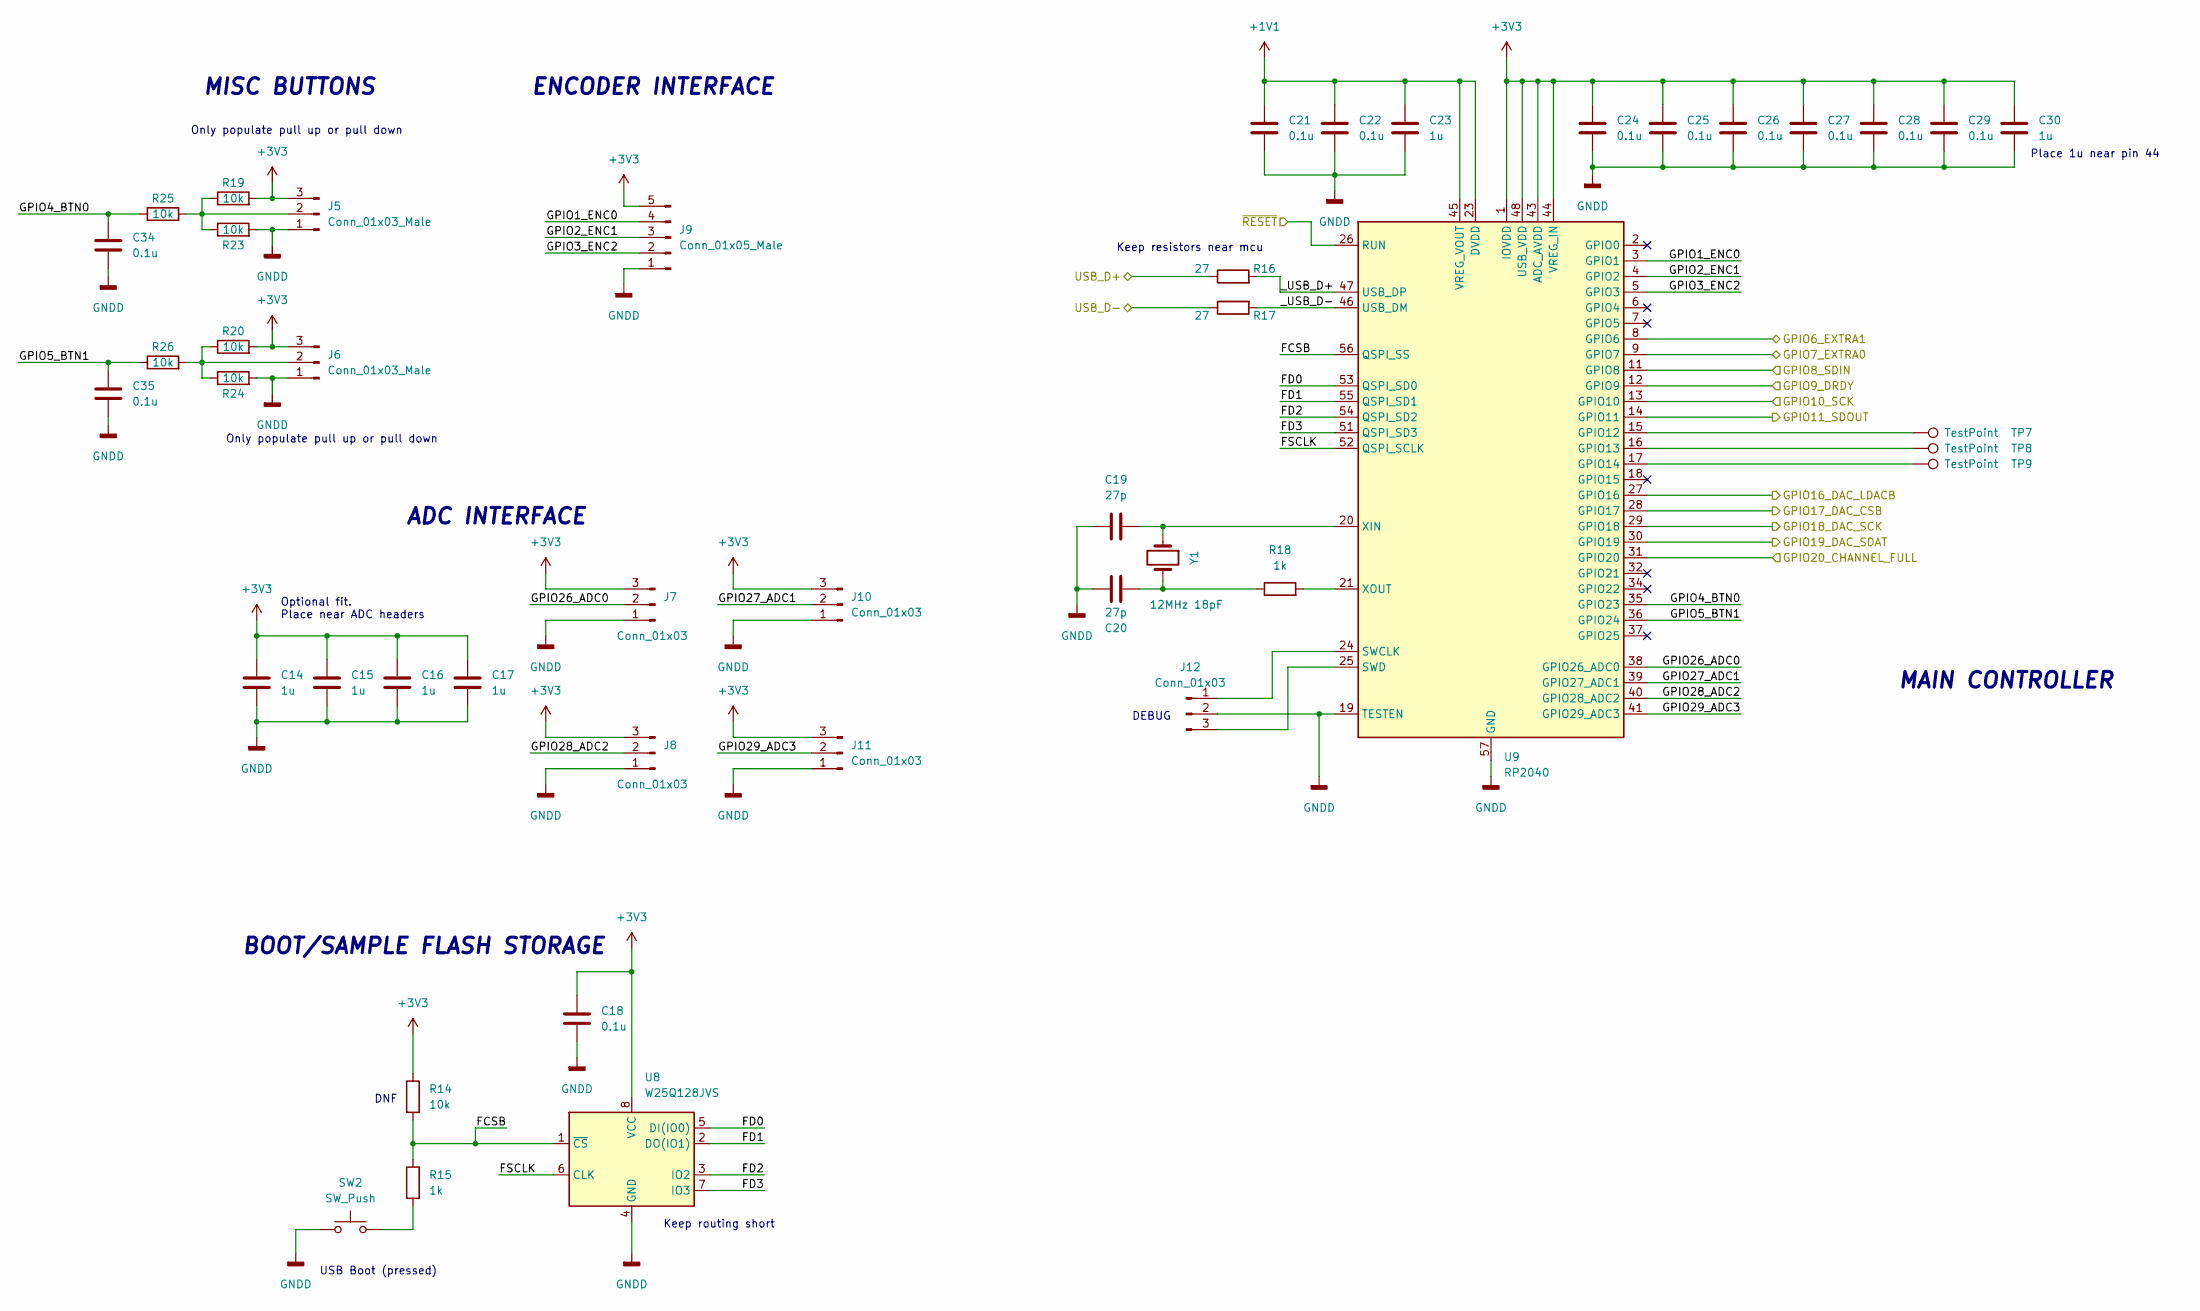
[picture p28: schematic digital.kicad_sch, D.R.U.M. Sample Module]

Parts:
C14, C15, C16, C17, C23, C30: 1u; C_0603_1608Metric_Pad1.08x0.95mm_HandSolder
C18, C21, C22, C24, C25, C26, C27, C28, C29, C34, C35: 0.1u; C_0603_1608Metric_Pad1.08x0.95mm_HandSolder
C19, C20: 27p; C_0603_1608Metric_Pad1.08x0.95mm_HandSolder
J5, J6: Conn_01x03_Male; PinHeader_1x03_P2.54mm_Vertical
J7, J8, J10, J11, J12: Conn_01x03; PinHeader_1x03_P2.54mm_Vertical
J9: Conn_01x05_Male; PinHeader_1x05_P2.54mm_Vertical
R14, R19, R20, R23, R24, R25, R26: 10k; R_0603_1608Metric_Pad0.98x0.95mm_HandSolder
R15, R18: 1k; R_0603_1608Metric_Pad0.98x0.95mm_HandSolder
R16, R17: 27; R_0603_1608Metric_Pad0.98x0.95mm_HandSolder
SW2: SW_Push; TE_ConnMSLPT5252CG1
TP7, TP8, TP9: TestPoint; TestPoint_Pad_D1.5mm
U8: W25Q128JVS; SOIC-8_5.23x5.23mm_P1.27mm
U9: RP2040; QFN-56-1EP_7x7mm_P0.4mm_EP3.2x3.2mm
Y1: 12MHz 18pF; Crystal_SMD_HC49-SD

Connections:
+1V1: C21.1, C22.1, C23.1, U9.23 (DVDD), U9.45 (VREG_VOUT), U9.50 (DVDD)
+3V3: C14.1, C15.1, C16.1, C17.1, C18.1, C24.1, C25.1, C26.1, C27.1, C28.1, C29.1, C30.1, J5.3, J6.3, J7.3, J8.3, J9.5, J10.3, J11.3, R14.1, R19.2, R20.2, U8.8 (VCC), U9.1 (IOVDD), U9.10 (IOVDD), U9.22 (IOVDD), U9.33 (IOVDD), U9.42 (IOVDD), U9.43 (ADC_AVDD), U9.44 (VREG_IN), U9.48 (USB_VDD), U9.49 (IOVDD); also elsewhere on the board
/CBUS_DRDY: U9.12 (GPIO9); also elsewhere on the board
/CBUS_EXTRA0: U9.9 (GPIO7); also elsewhere on the board
/CBUS_EXTRA1: U9.8 (GPIO6); also elsewhere on the board
/CBUS_SCK: U9.13 (GPIO10); also elsewhere on the board
/CBUS_SDIN: U9.11 (GPIO8); also elsewhere on the board
/CBUS_SDOUT: U9.14 (GPIO11); also elsewhere on the board
/CHANNEL_FULL: U9.31 (GPIO20); also elsewhere on the board
/D.R.U.M. Module Digital/FCSB: R14.2, R15.1, U8.1 (~CS), U9.56 (QSPI_SS)
/D.R.U.M. Module Digital/FD0: U8.5 (DI(IO0)), U9.53 (QSPI_SD0)
/D.R.U.M. Module Digital/FD1: U8.2 (DO(IO1)), U9.55 (QSPI_SD1)
/D.R.U.M. Module Digital/FD2: U8.3 (IO2), U9.54 (QSPI_SD2)
/D.R.U.M. Module Digital/FD3: U8.7 (IO3), U9.51 (QSPI_SD3)
/D.R.U.M. Module Digital/FSCLK: U8.6 (CLK), U9.52 (QSPI_SCLK)
/D.R.U.M. Module Digital/GPIO1_ENC0: J9.4, U9.3 (GPIO1)
/D.R.U.M. Module Digital/GPIO2_ENC1: J9.3, U9.4 (GPIO2)
/D.R.U.M. Module Digital/GPIO3_ENC2: J9.2, U9.5 (GPIO3)
/D.R.U.M. Module Digital/GPIO4_BTN0: C34.1, R25.1, U9.35 (GPIO23)
/D.R.U.M. Module Digital/GPIO5_BTN1: C35.1, R26.1, U9.36 (GPIO24)
/D.R.U.M. Module Digital/GPIO26_ADC0: J7.2, U9.38 (GPIO26_ADC0)
/D.R.U.M. Module Digital/GPIO27_ADC1: J10.2, U9.39 (GPIO27_ADC1)
/D.R.U.M. Module Digital/GPIO28_ADC2: J8.2, U9.40 (GPIO28_ADC2)
/D.R.U.M. Module Digital/GPIO29_ADC3: J11.2, U9.41 (GPIO29_ADC3)
/D.R.U.M. Module Digital/_USB_D+: R16.2, U9.47 (USB_DP)
/D.R.U.M. Module Digital/_USB_D-: R17.2, U9.46 (USB_DM)
/DAC_CSB: U9.28 (GPIO17); also elsewhere on the board
/DAC_LDACB: U9.27 (GPIO16); also elsewhere on the board
/DAC_SCK: U9.29 (GPIO18); also elsewhere on the board
/DAC_SDAT: U9.30 (GPIO19); also elsewhere on the board
/RUN: U9.26 (RUN); also elsewhere on the board
/USB_D+: R16.1; also elsewhere on the board
/USB_D-: R17.1; also elsewhere on the board
GND: C14.2, C15.2, C16.2, C17.2, C18.2, C19.1, C20.2, C21.2, C22.2, C23.2, C24.2, C25.2, C26.2, C27.2, C28.2, C29.2, C30.2, C34.2, C35.2, J5.1, J6.1, J7.1, J8.1, J9.1, J10.1, J11.1, J12.2, R23.2, R24.2, SW2.1, U8.4 (GND), U9.19 (TESTEN), U9.57 (GND); also elsewhere on the board
unnamed: C19.2, U9.20 (XIN), Y1.1
unnamed: C20.1, R18.1, Y1.2
unnamed: J5.2, R19.1, R23.1, R25.2
unnamed: J6.2, R20.1, R24.1, R26.2
unnamed: J12.1, U9.24 (SWCLK)
unnamed: J12.3, U9.25 (SWD)
unnamed: R15.2, SW2.2
unnamed: R18.2, U9.21 (XOUT)
unnamed: TP7.1, U9.15 (GPIO12)
unnamed: TP8.1, U9.16 (GPIO13)
unnamed: TP9.1, U9.17 (GPIO14)

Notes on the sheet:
Only populate pull up or pull down
Optional fit. Place near ADC headers
DEBUG
Keep resistors near mcu
USB Boot (pressed)
MAIN CONTROLLER
MISC BUTTONS
DNF
ENCODER INTERFACE
Keep routing short
Place 1u near pin 44
BOOT/SAMPLE FLASH STORAGE
ADC INTERFACE

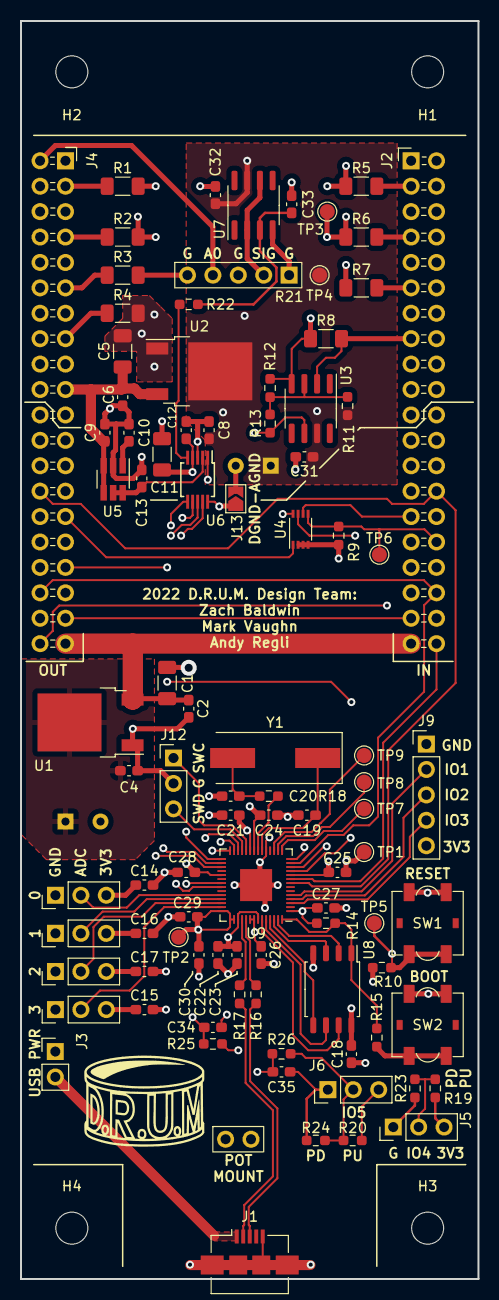
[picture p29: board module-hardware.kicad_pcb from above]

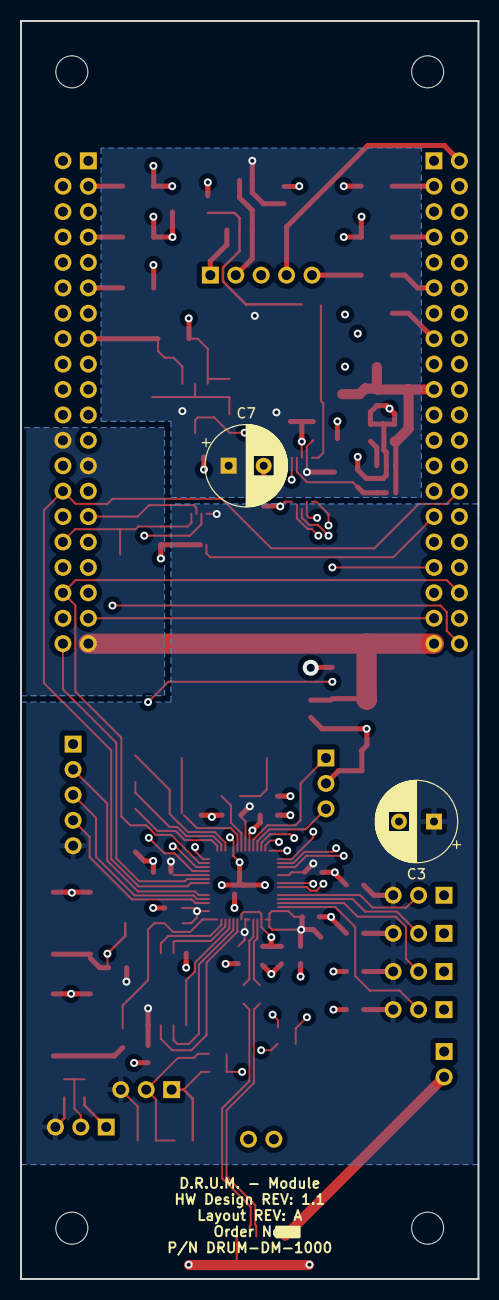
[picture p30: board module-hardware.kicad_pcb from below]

Board: 4 copper layers, 45.7 x 125.7 mm, 99 parts (2 on the bottom side), 68 nets.

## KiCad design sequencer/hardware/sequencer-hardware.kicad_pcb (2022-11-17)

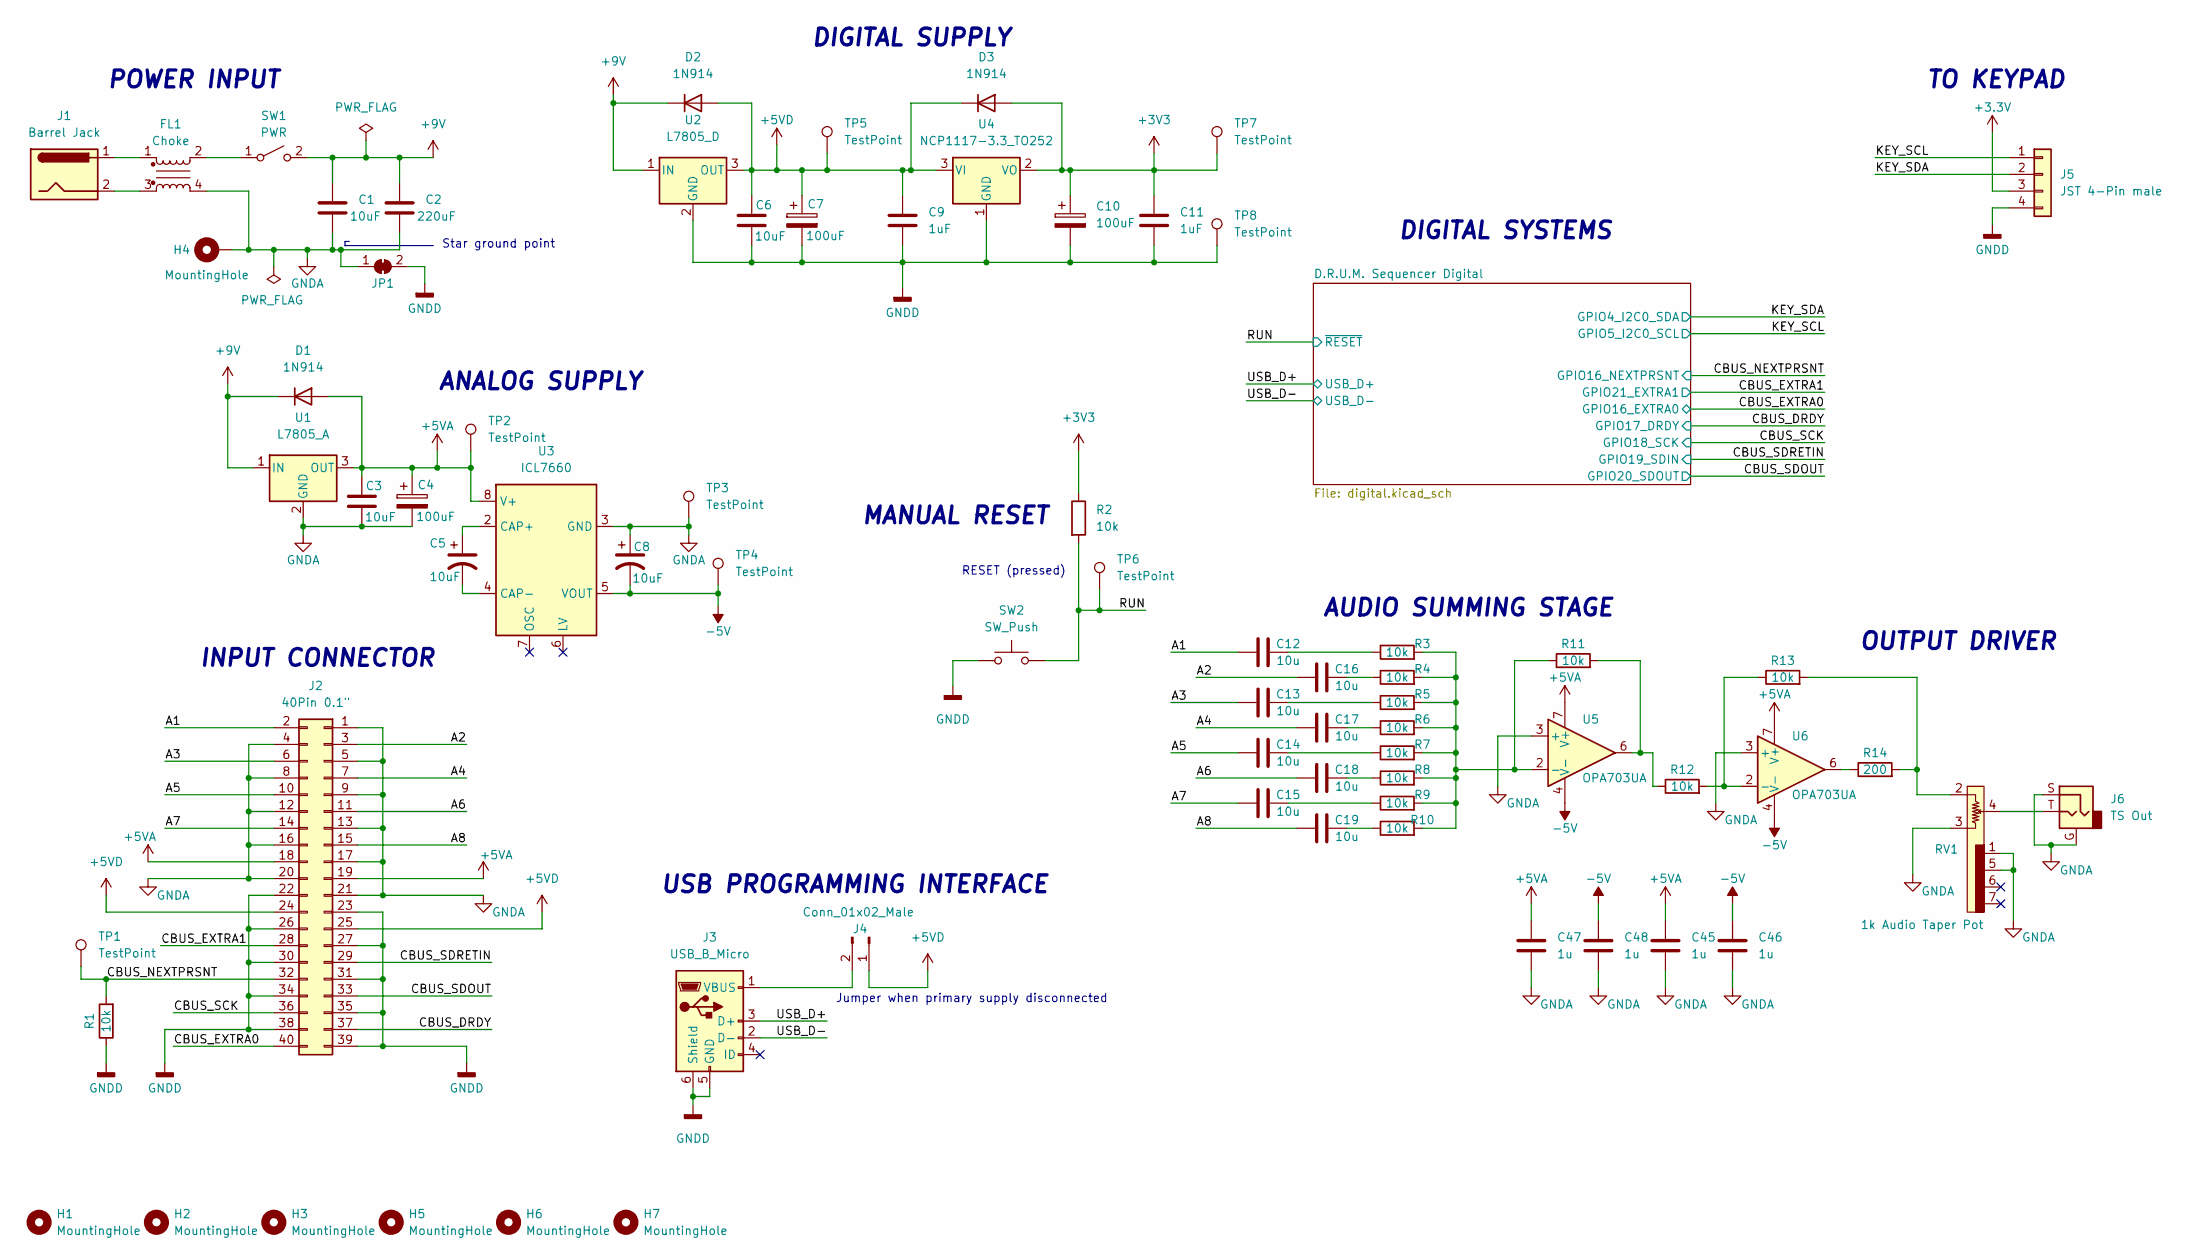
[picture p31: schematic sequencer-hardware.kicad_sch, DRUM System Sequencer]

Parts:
C1, C3, C5, C6, C8: 10uF; C_1206_3216Metric_Pad1.33x1.80mm_HandSolder
C2: 220uF; CP_Radial_D8.0mm_P3.50mm
C4, C7, C10: 100uF; CP_Radial_D8.0mm_P3.50mm
C9, C11: 1uF; C_0603_1608Metric_Pad1.08x0.95mm_HandSolder
C12, C13, C14, C15, C16, C17, C18, C19: 10u; C_1206_3216Metric_Pad1.33x1.80mm_HandSolder
C45, C46, C47, C48: 1u; C_0603_1608Metric_Pad1.08x0.95mm_HandSolder
D1, D2, D3: 1N914; D_DO-35_SOD27_P7.62mm_Horizontal
FL1: Choke; Choke_Schaffner_RN102-04-14.0x14.0mm
H1, H2, H3, H5, H6, H7: MountingHole; MountingHole_3.2mm_M3_ISO14580
H4: MountingHole; MountingHole_3.2mm_M3_ISO14580_Pad
J1: Barrel Jack; BarrelJack_Horizontal
J2: 40Pin 0.1"; PinHeader_2x20_P2.54mm_Horizontal
J3: USB_B_Micro; USB_Micro-B_Amphenol_10104110_Horizontal
J4: Conn_01x02_Male; PinHeader_1x02_P2.54mm_Vertical
J5: JST 4-Pin male; JST_PH_B4B-PH-K_1x04_P2.00mm_Vertical
J6: TS Out; Jack_6.35mm_Neutrik_NRJ6HF-AU_Horizontal
JP1: SolderJumper_2_Bridged; SolderJumper-2_P1.3mm_Bridged_Pad1.0x1.5mm
R1, R2, R3, R4, R5, R6, R7, R8, R9, R10, R11, R12, R13: 10k; R_0603_1608Metric_Pad0.98x0.95mm_HandSolder
R14: 200; R_0603_1608Metric_Pad0.98x0.95mm_HandSolder
RV1: 1k Audio Taper Pot; LINPOT-10KDB
SW1: PWR; PinHeader_1x02_P2.00mm_Vertical
SW2: SW_Push; TE_ConnMSLPT5252CG1
TP1, TP2, TP3, TP4, TP5, TP6, TP7, TP8: TestPoint; TestPoint_Pad_D1.5mm
U1: L7805_A; TO-220-3_Horizontal_TabDown
U2: L7805_D; TO-220-3_Horizontal_TabDown
U3: ICL7660; SOIC-8_3.9x4.9mm_P1.27mm
U4: NCP1117-3.3_TO252; TO-252-2
U5, U6: OPA703UA; SOIC-8_3.9x4.9mm_P1.27mm

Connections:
+5VA: C3.1, C4.1, C45.1, C47.1, D1.2 (A), J2.18, J2.19, TP2.1, U1.3 (OUT), U3.8 (V+), U5.7 (V+), U6.7 (V+)
+5VD: C6.1, C7.1, C9.1, D2.2 (A), D3.1 (K), J2.24, J2.25, J4.1, TP5.1, U2.3 (OUT), U4.3 (VI)
+9V: C1.1, C2.1, D1.1 (K), D2.1 (K), SW1.2 (B), U1.1 (IN), U2.1 (IN)
-5V: C8.2, C46.1, C48.1, TP4.1, U3.5 (VOUT), U5.4 (V-), U6.4 (V-)
/A1: C12.1, J2.2
/A2: C16.1, J2.3
/A3: C13.1, J2.6
/A4: C17.1, J2.7
/A5: C14.1, J2.10
/A6: C18.1, J2.11
/A7: C15.1, J2.14
/A8: C19.1, J2.15
/CBUS_DRDY: J2.37; also elsewhere on the board
/CBUS_EXTRA0: J2.40; also elsewhere on the board
/CBUS_EXTRA1: J2.28; also elsewhere on the board
/CBUS_NEXTPRSNT: J2.32, R1.2, TP1.1; also elsewhere on the board
/CBUS_SCK: J2.36; also elsewhere on the board
/CBUS_SDOUT: J2.33; also elsewhere on the board
/CBUS_SDRETIN: J2.29; also elsewhere on the board
/KEY_SCL: J5.1; also elsewhere on the board
/KEY_SDA: J5.2; also elsewhere on the board
/RUN: R2.2, SW2.2, TP6.1; also elsewhere on the board
/USB_D+: J3.3 (D+); also elsewhere on the board
/USB_D-: J3.2 (D-); also elsewhere on the board
GNDA: C1.2, C2.2, C3.2, C4.2, C8.1, C45.2, C46.2, C47.2, C48.2, FL1.4, H4.1, J2.1, J2.4, J2.5, J2.8, J2.9, J2.12, J2.13, J2.16, J2.17, J2.20, J2.21, J6.G, J6.S, JP1.1 (A), RV1.1, RV1.3, RV1.5, TP3.1, U1.2 (GND), U3.3 (GND), U5.3 (+), U6.3 (+)
GNDD: C6.2, C7.2, C9.2, C10.2, C11.2, J2.22, J2.23, J2.26, J2.27, J2.30, J2.31, J2.34, J2.35, J2.38, J2.39, J3.5 (GND), J3.6 (Shield), J5.4, JP1.2 (B), R1.1, SW2.1, TP8.1, U2.2 (GND), U4.1 (GND); also elsewhere on the board
unnamed: C5.1, U3.2 (CAP+)
unnamed: C5.2, U3.4 (CAP-)
unnamed: C12.2, R3.1
unnamed: C13.2, R5.1
unnamed: C14.2, R7.1
unnamed: C15.2, R9.1
unnamed: C16.2, R4.1
unnamed: C17.2, R6.1
unnamed: C18.2, R8.1
unnamed: C19.2, R10.1
unnamed: FL1.1, J1.1
unnamed: FL1.2, SW1.1 (A)
unnamed: FL1.3, J1.2
unnamed: J3.1 (VBUS), J4.2
unnamed: J6.T, RV1.4
unnamed: R3.2, R4.2, R5.2, R6.2, R7.2, R8.2, R9.2, R10.2, R11.1, U5.2 (-)
unnamed: R11.2, R12.1, U5.6
unnamed: R12.2, R13.1, U6.2 (-)
unnamed: R13.2, R14.2, RV1.2
unnamed: R14.1, U6.6

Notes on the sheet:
OUTPUT DRIVER
Jumper when primary supply disconnected
TO KEYPAD
RESET (pressed)
MANUAL RESET
INPUT CONNECTOR
DIGITAL SYSTEMS
DIGITAL SUPPLY
USB PROGRAMMING INTERFACE
AUDIO SUMMING STAGE
ANALOG SUPPLY
POWER INPUT
Star ground point

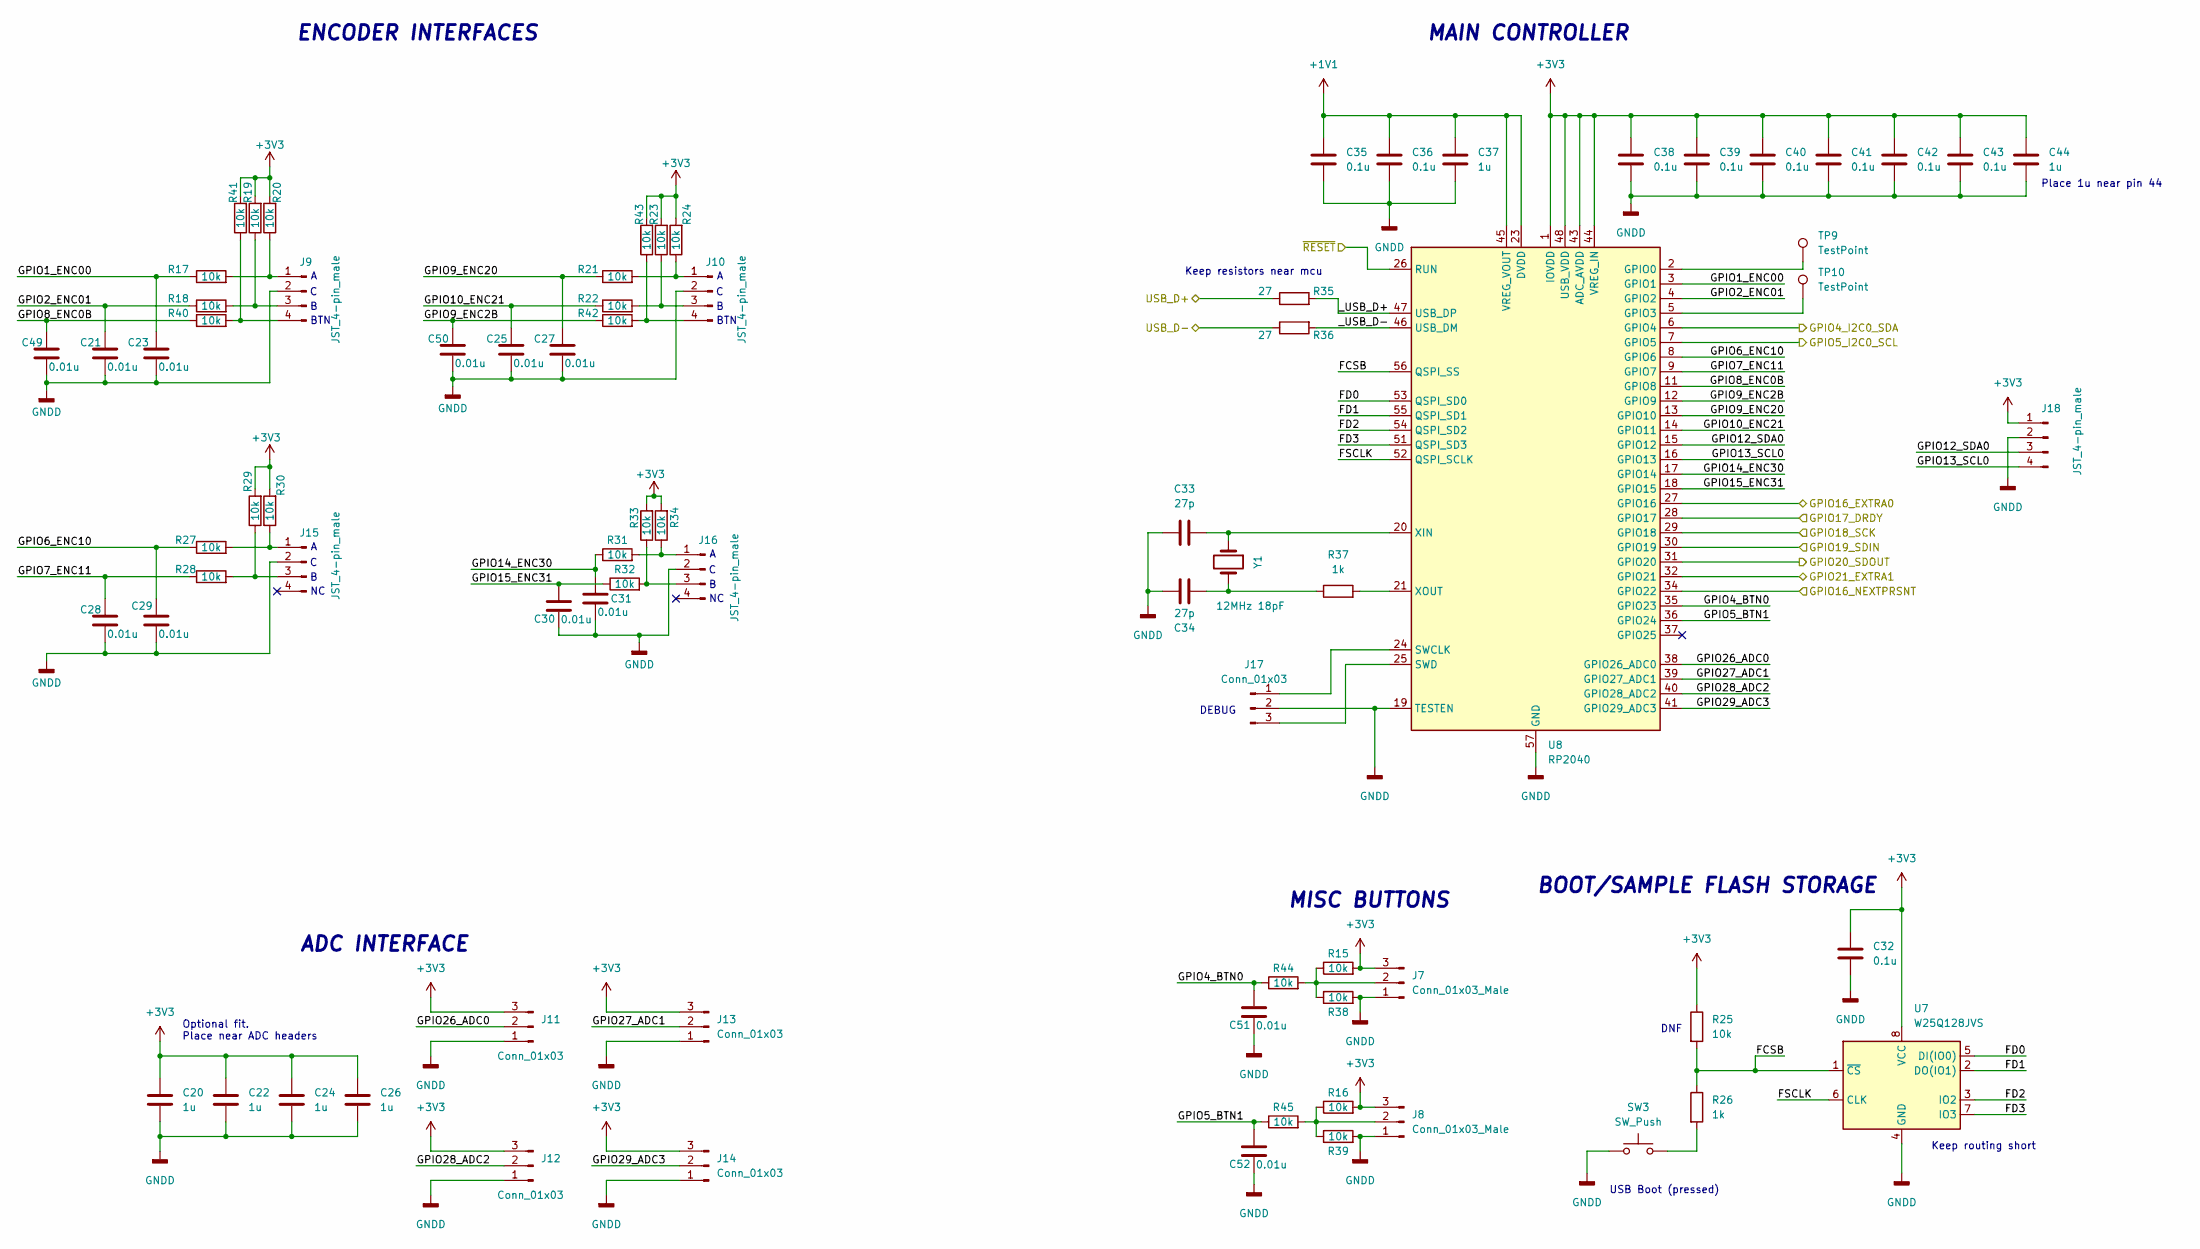
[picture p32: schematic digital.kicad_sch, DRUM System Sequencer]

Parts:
C20, C22, C24, C26, C37, C44: 1u; C_0603_1608Metric_Pad1.08x0.95mm_HandSolder
C21, C23, C25, C27, C28, C29, C30, C31, C49, C50, C51, C52: 0.01u; C_0805_2012Metric_Pad1.18x1.45mm_HandSolder
C32, C35, C36, C38, C39, C40, C41, C42, C43: 0.1u; C_0603_1608Metric_Pad1.08x0.95mm_HandSolder
C33, C34: 27p; C_0603_1608Metric_Pad1.08x0.95mm_HandSolder
J7, J8: Conn_01x03_Male; PinHeader_1x03_P2.54mm_Vertical
J9, J10, J15, J16, J18: JST_4-pin_male; JST_PH_B4B-PH-K_1x04_P2.00mm_Vertical
J11, J12, J13, J14, J17: Conn_01x03; PinHeader_1x03_P2.54mm_Vertical
R15, R16, R17, R18, R19, R20, R21, R22, R23, R24, R25, R27, R28, R29, R30, R31, R32, R33, R34, R38, R39, R40, R41, R42, R43, R44, R45: 10k; R_0603_1608Metric_Pad0.98x0.95mm_HandSolder
R26, R37: 1k; R_0603_1608Metric_Pad0.98x0.95mm_HandSolder
R35, R36: 27; R_0603_1608Metric_Pad0.98x0.95mm_HandSolder
SW3: SW_Push; TE_ConnMSLPT5252CG1
TP9, TP10: TestPoint; TestPoint_Pad_D1.5mm
U7: W25Q128JVS; SOIC-8_5.23x5.23mm_P1.27mm
U8: RP2040; QFN-56-1EP_7x7mm_P0.4mm_EP3.2x3.2mm
Y1: 12MHz 18pF; Crystal_SMD_HC49-SD

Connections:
+1V1: C35.1, C36.1, C37.1, U8.23 (DVDD), U8.45 (VREG_VOUT), U8.50 (DVDD)
/CBUS_DRDY: U8.28 (GPIO17); also elsewhere on the board
/CBUS_EXTRA0: U8.27 (GPIO16); also elsewhere on the board
/CBUS_EXTRA1: U8.32 (GPIO21); also elsewhere on the board
/CBUS_NEXTPRSNT: U8.34 (GPIO22); also elsewhere on the board
/CBUS_SCK: U8.29 (GPIO18); also elsewhere on the board
/CBUS_SDOUT: U8.31 (GPIO20); also elsewhere on the board
/CBUS_SDRETIN: U8.30 (GPIO19); also elsewhere on the board
/D.R.U.M. Sequencer Digital/FCSB: R25.2, R26.1, U7.1 (~CS), U8.56 (QSPI_SS)
/D.R.U.M. Sequencer Digital/FD0: U7.5 (DI(IO0)), U8.53 (QSPI_SD0)
/D.R.U.M. Sequencer Digital/FD1: U7.2 (DO(IO1)), U8.55 (QSPI_SD1)
/D.R.U.M. Sequencer Digital/FD2: U7.3 (IO2), U8.54 (QSPI_SD2)
/D.R.U.M. Sequencer Digital/FD3: U7.7 (IO3), U8.51 (QSPI_SD3)
/D.R.U.M. Sequencer Digital/FSCLK: U7.6 (CLK), U8.52 (QSPI_SCLK)
/D.R.U.M. Sequencer Digital/GPIO1_ENC00: C23.1, R17.1, U8.3 (GPIO1)
/D.R.U.M. Sequencer Digital/GPIO2_ENC01: C21.1, R18.1, U8.4 (GPIO2)
/D.R.U.M. Sequencer Digital/GPIO4_BTN0: C51.1, R44.1, U8.35 (GPIO23)
/D.R.U.M. Sequencer Digital/GPIO5_BTN1: C52.1, R45.1, U8.36 (GPIO24)
/D.R.U.M. Sequencer Digital/GPIO6_ENC10: C29.1, R27.1, U8.8 (GPIO6)
/D.R.U.M. Sequencer Digital/GPIO7_ENC11: C28.1, R28.1, U8.9 (GPIO7)
/D.R.U.M. Sequencer Digital/GPIO8_ENC0B: C49.1, R40.1, U8.11 (GPIO8)
/D.R.U.M. Sequencer Digital/GPIO9_ENC2B: C50.1, R42.1, U8.12 (GPIO9)
/D.R.U.M. Sequencer Digital/GPIO9_ENC20: C27.1, R21.1, U8.13 (GPIO10)
/D.R.U.M. Sequencer Digital/GPIO10_ENC21: C25.1, R22.1, U8.14 (GPIO11)
/D.R.U.M. Sequencer Digital/GPIO12_SDA0: J18.3, U8.15 (GPIO12)
/D.R.U.M. Sequencer Digital/GPIO13_SCL0: J18.4, U8.16 (GPIO13)
/D.R.U.M. Sequencer Digital/GPIO14_ENC30: C31.1, R31.1, U8.17 (GPIO14)
/D.R.U.M. Sequencer Digital/GPIO15_ENC31: C30.1, R32.1, U8.18 (GPIO15)
/D.R.U.M. Sequencer Digital/GPIO26_ADC0: J11.2, U8.38 (GPIO26_ADC0)
/D.R.U.M. Sequencer Digital/GPIO27_ADC1: J13.2, U8.39 (GPIO27_ADC1)
/D.R.U.M. Sequencer Digital/GPIO28_ADC2: J12.2, U8.40 (GPIO28_ADC2)
/D.R.U.M. Sequencer Digital/GPIO29_ADC3: J14.2, U8.41 (GPIO29_ADC3)
/D.R.U.M. Sequencer Digital/_USB_D+: R35.2, U8.47 (USB_DP)
/D.R.U.M. Sequencer Digital/_USB_D-: R36.2, U8.46 (USB_DM)
/KEY_SCL: U8.7 (GPIO5); also elsewhere on the board
/KEY_SDA: U8.6 (GPIO4); also elsewhere on the board
/RUN: U8.26 (RUN); also elsewhere on the board
/USB_D+: R35.1; also elsewhere on the board
/USB_D-: R36.1; also elsewhere on the board
GNDD: C20.2, C21.2, C22.2, C23.2, C24.2, C25.2, C26.2, C27.2, C28.2, C29.2, C30.2, C31.2, C32.2, C33.1, C34.2, C35.2, C36.2, C37.2, C38.2, C39.2, C40.2, C41.2, C42.2, C43.2, C44.2, C49.2, C50.2, C51.2, C52.2, J7.1, J8.1, J9.2, J10.2, J11.1, J12.1, J13.1, J14.1, J15.2, J16.2, J17.2, J18.2, R38.2, R39.2, SW3.1, U7.4 (GND), U8.19 (TESTEN), U8.57 (GND); also elsewhere on the board
unnamed: C33.2, U8.20 (XIN), Y1.1
unnamed: C34.1, R37.1, Y1.2
unnamed: J7.2, R15.1, R38.1, R44.2
unnamed: J8.2, R16.1, R39.1, R45.2
unnamed: J9.1, R17.2, R20.1
unnamed: J9.3, R18.2, R19.1
unnamed: J9.4, R40.2, R41.1
unnamed: J10.1, R21.2, R24.1
unnamed: J10.3, R22.2, R23.1
unnamed: J10.4, R42.2, R43.1
unnamed: J15.1, R27.2, R30.1
unnamed: J15.3, R28.2, R29.1
unnamed: J16.1, R31.2, R34.1
unnamed: J16.3, R32.2, R33.1
unnamed: J17.1, U8.24 (SWCLK)
unnamed: J17.3, U8.25 (SWD)
unnamed: R26.2, SW3.2
unnamed: R37.2, U8.21 (XOUT)
unnamed: TP9.1, U8.2 (GPIO0)
unnamed: TP10.1, U8.5 (GPIO3)

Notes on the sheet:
ENCODER INTERFACES
DEBUG
ADC INTERFACE
MAIN CONTROLLER
BTN
DNF
Optional fit. Place near ADC headers
Place 1u near pin 44
BOOT/SAMPLE FLASH STORAGE
MISC BUTTONS
Keep resistors near mcu
USB Boot (pressed)
Keep routing short

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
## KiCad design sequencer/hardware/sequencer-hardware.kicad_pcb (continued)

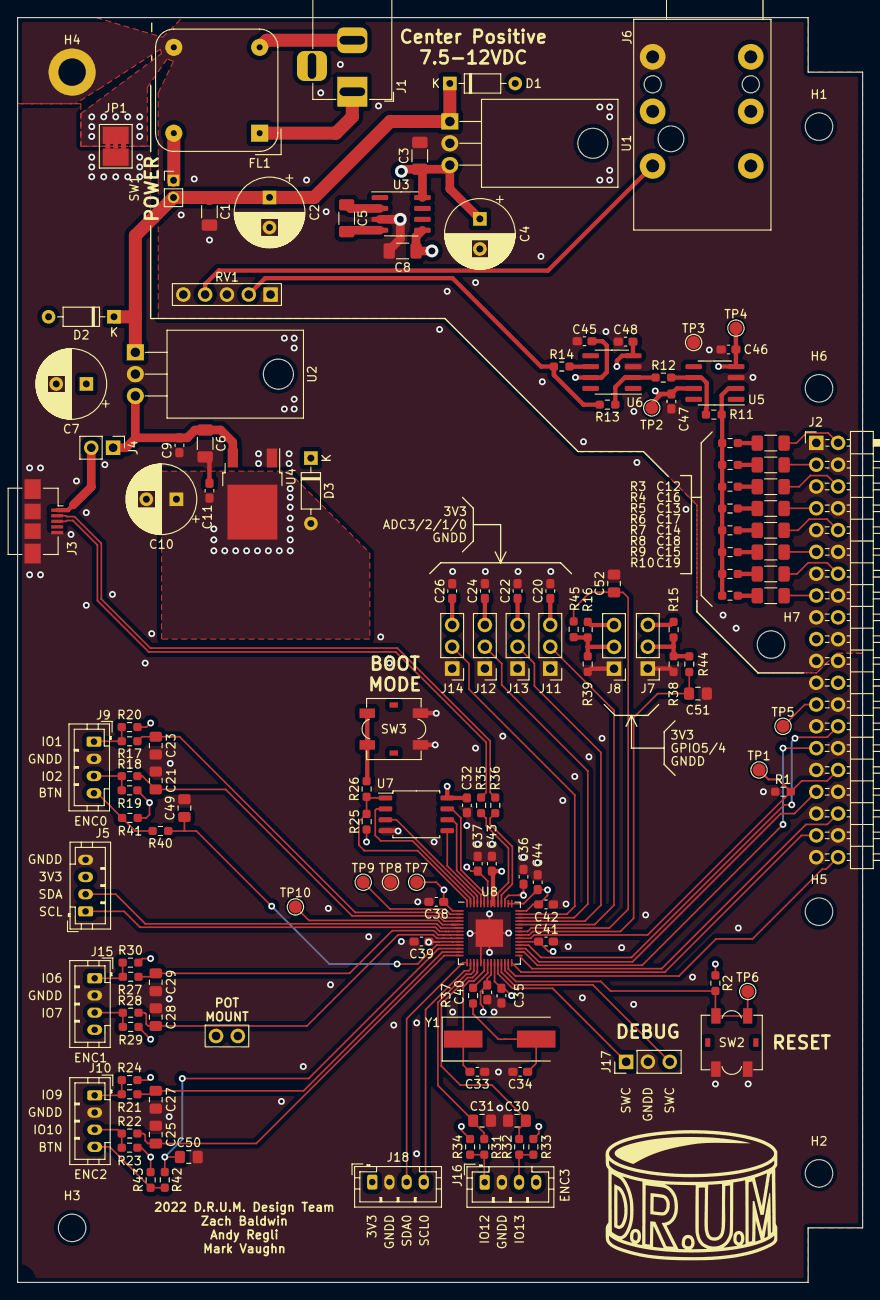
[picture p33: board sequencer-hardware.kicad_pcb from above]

Board: 4 copper layers, 98.4 x 147.3 mm, 150 parts (0 on the bottom side), 94 nets.

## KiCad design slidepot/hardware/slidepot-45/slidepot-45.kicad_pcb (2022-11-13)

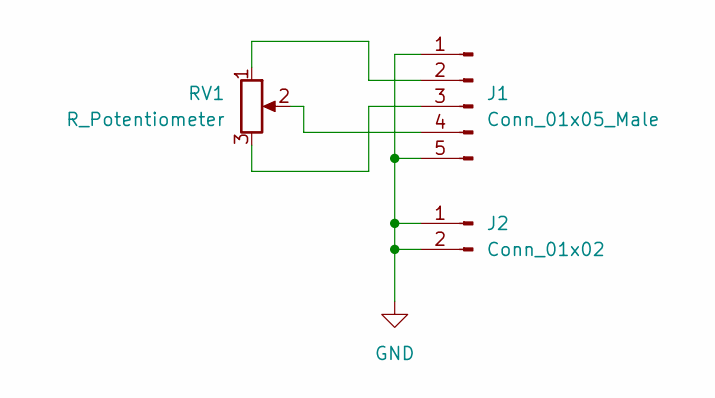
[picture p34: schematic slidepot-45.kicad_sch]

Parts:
J1: Conn_01x05_Male; PinHeader_1x05_P2.54mm_Vertical
J2: Conn_01x02; PinHeader_1x02_P2.54mm_Vertical
RV1: R_Potentiometer; Potentiometer_Bourns_PTA4543_Single_Slide

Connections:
GND: J1.1, J1.5, J2.1, J2.2
unnamed: J1.2, RV1.1
unnamed: J1.3, RV1.3
unnamed: J1.4, RV1.2

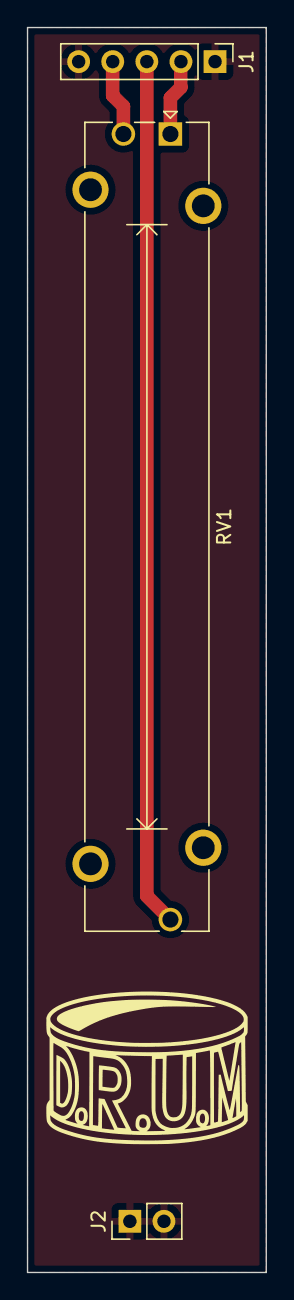
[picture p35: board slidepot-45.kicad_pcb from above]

Board: 2 copper layers, 17.8 x 92.7 mm, 3 parts (0 on the bottom side), 4 nets.

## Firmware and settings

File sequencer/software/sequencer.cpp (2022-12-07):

/**
 * SEQUENCER CONTROLLER
 * 
 * Authors:
 * Zach Baldwin
 * Andy Regli
 * Mark Vaughn
 *
 */

#include "pico/stdlib.h"
#include "pico/binary_info.h"
#include "pico/util/queue.h"
#include "pico/multicore.h"
#include "pico/critical_section.h"
#include "hardware/gpio.h"
#include "hardware/i2c.h"

#include "Adafruit_Lib/Adafruit_NeoTrellis.h"
#include "Adafruit_Lib/seesaw_neopixel.h"
#include "Adafruit_Lib/Adafruit_NeoTrellis.h"
#include "Adafruit_Lib/Arduino.h"
#include "Adafruit_Lib/Adafruit_SSD1306.h"
#include "adafruit_Lib/Adafruit_GFX.h"

// Fonts
#include "Adafruit_Lib/Fonts/FreeMonoBoldOblique12pt7b.h"

#include "sequencer.pio.h"
#include "serbus.h"
#include "sequencer.h"

time_sig_t time_signatures[] = {
    {3, 4, 12},
    {4, 4, 16},
    {7, 8, 14}
};

#define TSIG_MAX (sizeof(time_signatures)/sizeof(*time_signatures))


// All of these can be modified by the ISRs
volatile bool is_running;
volatile int bpm;
volatile bool has_bpm_changed;
volatile unsigned int time_sig;
volatile unsigned int current_beat;
volatile signed int current_ubeat;
volatile unsigned int max_beat;
volatile alarm_id_t alarm_clear_grid_id;
repeating_timer_t timer;
critical_section_t oled_spinlock;
int connected_module_count;

struct {
    volatile bool has_mod_irq;
    volatile beat_data_t beats[16];
    int last_veloc; // The result of the last velocity change
    volatile bool do_screen_update;
    volatile bool is_mod_selected; // Indicates that a module's pattern is currently in the beats array
    int selected_mod_index;

    queue_t queue_button_event;

    mutex_t mutex_has_mod_irq;
    mutex_t mutex_beats;
    mutex_t mutex_last_veloc;
    mutex_t mutex_do_screen_update;
} mod_data;


struct {
    uint tx_sm;
    PIO tx_pio;
    uint tx_offs;
    uint rx_sm;
    PIO rx_pio;
    uint rx_offs;
} intermodule_pio;

Adafruit_NeoTrellis trellis;
Adafruit_SSD1306 display(SCREEN_WIDTH, SCREEN_HEIGHT, &Wire, -1);

int main ()
{
    // Hardware init
    stdio_init_all();

    // Init I2C for the screen and keypad
    gpio_set_function(KEYPAD_SDA, GPIO_FUNC_I2C);
    gpio_set_function(KEYPAD_SCL, GPIO_FUNC_I2C);
    gpio_pull_up(KEYPAD_SDA);
    gpio_pull_up(KEYPAD_SCL);

    // Output pins
    gpio_init(GPIO_CBUS_DRDY);
    gpio_set_dir(GPIO_CBUS_DRDY, GPIO_OUT);
    gpio_put(GPIO_CBUS_DRDY, 1); // Initially not transmitting. This signal is inverted
    gpio_init(MOD_TEMPO_SYNC);
    gpio_set_dir(MOD_TEMPO_SYNC, GPIO_OUT);
    gpio_put(MOD_TEMPO_SYNC, 1);

    // This clock line will be reinitialied within the PIO TX init
    // It needs to be toggled to reset the module's state machines
    // gpio_init(GPIO_CBUS_SCK);
    // gpio_set_dir(GPIO_CBUS_SCK, GPIO_OUT);
    // gpio_put(GPIO_CBUS_SCK, 1);
    // gpio_put(GPIO_CBUS_SCK, 0);


    // Inputs
    gpio_init(TEMPO_ENC0);
    gpio_init(TEMPO_ENC1);
    gpio_init(PLYSTP_BTN);
    gpio_init(TSIG_ENC0);
    gpio_init(TSIG_ENC1);
    gpio_init(CLEAR_BTN);
    gpio_init(GPIO_CBUS_NXTPR);
    gpio_set_dir(TEMPO_ENC0, GPIO_IN);
    gpio_set_dir(TEMPO_ENC1, GPIO_IN);
    gpio_set_dir(PLYSTP_BTN, GPIO_IN);
    gpio_set_dir(TSIG_ENC0, GPIO_IN);
    gpio_set_dir(TSIG_ENC1, GPIO_IN);
    gpio_set_dir(CLEAR_BTN, GPIO_IN);
    gpio_set_dir(GPIO_CBUS_NXTPR, GPIO_IN);

    gpio_init(MOD_STAT_IRQ);
    gpio_set_dir(MOD_STAT_IRQ, GPIO_IN);
    gpio_pull_up(MOD_STAT_IRQ);

    // PIO state machines for intermodule communication (IMC)
    // NOTE: the TX and RX programs MUST be run on separate
    // state machines since each requires an 8-word deep FIFO
    intermodule_pio.tx_pio = pio0;
    intermodule_pio.tx_sm = pio_claim_unused_sm(intermodule_pio.tx_pio, true);
    intermodule_pio.tx_offs = pio_add_program(intermodule_pio.tx_pio, &seq_tx_program);
    seq_tx_init(
        intermodule_pio.tx_pio,
        intermodule_pio.tx_sm,
        intermodule_pio.tx_offs,
        GPIO_CBUS_SCK,
        GPIO_CBUS_SDOUT
        );

    intermodule_pio.rx_pio = pio1;
    intermodule_pio.rx_sm = pio_claim_unused_sm(intermodule_pio.rx_pio, true);
    intermodule_pio.rx_offs = pio_add_program(intermodule_pio.rx_pio, &seq_rx_program);
    seq_rx_init(
        intermodule_pio.rx_pio,
        intermodule_pio.rx_sm,
        intermodule_pio.rx_offs,
        GPIO_CBUS_SCK,
        GPIO_CBUS_SDIN,
        GPIO_CBUS_DRDY
        );


    // Initialize Sequencer states
    is_running = false;
    mod_data.is_mod_selected = false;
    mod_data.has_mod_irq = false;
    mod_data.do_screen_update = true;
    mod_data.last_veloc = 0;
    mod_data.selected_mod_index = 0;
    has_bpm_changed = false;
    bpm = BPM_DEFAULT;
    time_sig = TS_DEFAULT;
    max_beat = time_signatures[time_sig].max_ticks;
    current_beat = max_beat;
    current_ubeat = 0;
    connected_module_count = get_connected_module_count();

    critical_section_init(&oled_spinlock);

    // Startup CORE 1 to handle the IMC
    multicore_launch_core1(module_data_controller);
    mutex_init(&mod_data.mutex_has_mod_irq);
    mutex_init(&mod_data.mutex_beats);
    mutex_init(&mod_data.mutex_last_veloc);
    mutex_init(&mod_data.mutex_do_screen_update);
    queue_init(
        &mod_data.queue_button_event,
        sizeof(beat_update_t),
        BEAT_DATA_QUEUE_LEN
        );

    // Delay for power supply OLED issues
    sleep_ms(250);
    
    // Casually ignoring the return value
    trellis.begin(NEO_TRELLIS_ADDR, -1);
    
    // CAPVCC = gen drive voltage from 3V3 pin
    display.begin(SSD1306_SWITCHCAPVCC, SCREEN_ADDRESS);
    display.setFont(&FreeMonoBoldOblique12pt7b);
    display.setTextColor(WHITE);

    // Show splash screen
    display.display();    
    
    // Activate all keys and set callbacks
    for(int i=0; i<NEO_TRELLIS_NUM_KEYS; i++){
        trellis.activateKey(i, SEESAW_KEYPAD_EDGE_RISING);
        trellis.activateKey(i, SEESAW_KEYPAD_EDGE_FALLING);
        trellis.registerCallback(i, isr_pad_event);
    }

    // Do a little animation to show we're on
    for (uint16_t i=0; i<trellis.pixels.numPixels(); i++) {
        trellis.pixels.setPixelColor(i, 255, 255, 255);
        trellis.pixels.show();
        sleep_ms(50);
    }
    for (uint16_t i=0; i<trellis.pixels.numPixels(); i++) {
        trellis.pixels.setPixelColor(i, 0x000000);
        trellis.pixels.show();
        sleep_ms(50);
    }

    // Clear display
    display.clearDisplay();
    display.display();

    // Register ISRs to GPIO and Timer events
    // Tempo Encoder
    gpio_set_irq_enabled_with_callback(
        TEMPO_ENC0,
        GPIO_IRQ_EDGE_FALL,
        true, // Enable interrupt
        &isr_gpio_handler
        );

    // Time signature encoder
    gpio_set_irq_enabled(
        TSIG_ENC0,
        GPIO_IRQ_EDGE_FALL,
        true // Enable interrupt
        );

    // Play / pause button
    gpio_set_irq_enabled(
        PLYSTP_BTN,
        GPIO_IRQ_EDGE_FALL,
        true // Enable interrupt
        );

    // Clear beat pad button
    gpio_set_irq_enabled(
        CLEAR_BTN,
        GPIO_IRQ_EDGE_FALL | GPIO_IRQ_EDGE_RISE,
        true // Enable interrupt
        );

    // Module selection status update
    gpio_set_irq_enabled(
        MOD_STAT_IRQ,
        GPIO_IRQ_EDGE_RISE,
        true // Enable interrupt
        );

    uint32_t tx[] = {
        (const uint32_t)0xaaaaaaaa,
        (const uint32_t)0xffffffff,
        (const uint32_t)0x80808080,
        (const uint32_t)0xc3c3c3c3
    };

    uint32_t rx[8];

    // Main event loop
    while (1) {
        update_screen();
        trellis.read();  // interrupt management does all the work! :)
        update_buttons();
        sleep_ms(20);
        // intermodule_serbus_txrx(
        //     intermodule_pio.rx_pio,
        //     intermodule_pio.rx_sm,
        //     intermodule_pio.tx_pio,
        //     intermodule_pio.tx_sm,
        //     rx,
        //     tx,
        //     4,
        //     GPIO_CBUS_DRDY,
        //     GPIO_CBUS_SCK
        //     );
        // for (size_t i = 0; i < 3; ++i) {
        //     if (tx[i] != rx[i+1]) {
        //         is_running = false;
        //     }
        // }
    }
}


/**
 * Reset the sequencer grid
 */
void clear_beats(void)
{
    mutex_enter_blocking(&mod_data.mutex_beats);

    // 16 beats
    for (size_t i = 0; i < 16; ++i) {
        mod_data.beats[i].ubeat = 0;
        mod_data.beats[i].veloc = 0;
    }

    mutex_exit(&mod_data.mutex_beats);
}


/**
 * Updates the screen. Displays the current tempo, time signature,
 * Play/Pause status, and relevant information during module programming
 */
void update_screen(void)
{
    uint32_t owner;
    bool update;

    // Check if there needs to be updates sent to the screen
    critical_section_enter_blocking(&oled_spinlock);
    update = mutex_try_enter(&mod_data.mutex_do_screen_update, &owner);
    mutex_exit(&mod_data.mutex_do_screen_update);
    critical_section_exit(&oled_spinlock);
    if (update) {
        update = mod_data.do_screen_update;
    }

    // If there's updates to do, send them
    if (update) {
        display.clearDisplay();

        // Display BPM
        display.setCursor(0,18); // Magic numbers for field locations on screen
        display.print(bpm, DEC);

        // Display time signature
        display.setCursor(84, 18);
        display.print(time_signatures[time_sig].beats, DEC);
        display.print('/');
        display.print(time_signatures[time_sig].measure, DEC);

        // Display last velocity update
        display.setCursor(0, 60);
        mutex_enter_blocking(&mod_data.mutex_last_veloc);
        display.print(mod_data.last_veloc, DEC);
        mutex_exit(&mod_data.mutex_last_veloc);

        display.setCursor(30, 60);
        display.print(connected_module_count);

        // Send data to display
        display.display();

        // Done with update
        mod_data.do_screen_update = false;
    }
}


/**
 * Starts the micro beat tick timer
 */
bool start_timer()
{
    // Negative timeout means exact delay (rather than delay between callbacks)
    return add_repeating_timer_us(
        TEMPO_TICK_US_CALC,
        isr_timer,
        NULL,
        &timer
        );
}


/**
 * Stops the micro beat timer
 */
bool stop_timer()
{
    return cancel_repeating_timer(&timer);
}


/**
 * Update the colors of the button matrix based on the current sequencer
 * state.
 */
void update_buttons(void)
{
    uint8_t r, g, b;
    mutex_enter_blocking(&mod_data.mutex_beats);
    for (size_t i = 0; i < 16; ++i) {
        if (is_running && i == current_beat) {
            trellis.pixels.setPixelColor(i, 255, 255, 255);
        }
        else if (i >= max_beat) {
            trellis.pixels.setPixelColor(i, 64, 64, 64); // Light red
        }
        else if (mod_data.beats[i].veloc > 0) {
            r = velocity_colors[mod_data.beats[i].veloc][0];
            g = velocity_colors[mod_data.beats[i].veloc][1];
            b = velocity_colors[mod_data.beats[i].veloc][2];
            trellis.pixels.setPixelColor(i, r, g, b);
        }
        else {
            trellis.pixels.setPixelColor(i, 0, 0, 0);
        }
    }
    mutex_exit(&mod_data.mutex_beats);
    trellis.pixels.show();
}


/**
 * Determines the GPIO which triggered the interrupt and calls it's handler
 */
void isr_gpio_handler(unsigned int gpio, uint32_t event)
{
    switch (gpio) {
    case TEMPO_ENC0:
        isr_tempo_encoder(gpio, event);
        break;

    case PLYSTP_BTN:
        isr_play_pause(gpio, event);
        break;

    case TSIG_ENC0:
        isr_time_sig_encoder(gpio, event);
        break;

    case CLEAR_BTN:
        isr_clear_pattern_start_timeout(gpio, event);
        break;

    case MOD_STAT_IRQ:
        isr_module_status(gpio, event);
        break;
        
    default:
        return;
    }
}


/**
 * Handles generation of synchronization "tick" pulses with all modules
 */
bool isr_timer(repeating_timer_t *rt)
{
    // Update the current beat
    if (is_running) {
        if (current_ubeat == 0) {
            ++current_beat;
            if (current_beat >= max_beat) {
                current_beat = 0;
            }

            // Signal to modules start of a new beat
            gpio_put(MOD_TEMPO_SYNC, false);
            add_alarm_in_us(
                (current_beat == 0) ? ALARM_TEMPO_SAMPLE_Z_US : ALARM_TEMPO_SAMPLE_NZ_US,
                alarm_seq_beat_callback,
                NULL,
                false
                );
        }
        else if (current_ubeat == MAX_UBEAT) {
            current_ubeat = MIN_UBEAT;
        }
        ++current_ubeat;
    }

    // A bit of a hack, but adjust the timer's timeout value
    // based on the current BPM setting
    if (has_bpm_changed) {
        rt->delay_us = TEMPO_TICK_US_CALC;
        has_bpm_changed = false;
    }
    
    return true; // keep repeating    
}


/**
 * Called after the tempo timer fires. Delay between the tempo timer
 * and this is dependent on the beat number.
 */
int64_t alarm_seq_beat_callback(alarm_id_t id, void *user_data)
{
    gpio_put(MOD_TEMPO_SYNC, true);
    return 0; // Don't trigger another callback
}


/**
 * Handles detection of module status changes via the CBUS_EXTRA 
 * interrupt line
 * 
 * @param The GPIO pin number
 * @param The GPIO event type */
void isr_module_status(unsigned int gpio, uint32_t event)
{
    uint32_t owner;
    mutex_try_enter(&mod_data.mutex_has_mod_irq, &owner);
    mod_data.has_mod_irq = true;
    mutex_exit(&mod_data.mutex_has_mod_irq);
}


/**
 * Handles updating of the global tempo value when the tempo encoder
 * is rotated
 * 
 * @param The GPIO pin number
 * @param The GPIO event type
 */
void isr_tempo_encoder(unsigned int gpio, uint32_t event)
{
    if (gpio_get(TEMPO_ENC1) == 1) { // "Forward"
        if (bpm < BPM_MAX) {
            ++bpm;
        }
    } else { // Backward
        if (bpm > BPM_MIN) {
            --bpm;
        }
    }
    has_bpm_changed = true;

    // Tell screen to do an update
    mutex_enter_blocking(&mod_data.mutex_do_screen_update);
    mod_data.do_screen_update = true;
    mutex_exit(&mod_data.mutex_do_screen_update);
}


/**
 * Handles the toggling of the is_running flag based on the play/pause
 * button input
 * 
 * @param The GPIO pin number
 * @param The GPIO event type
 */
void isr_play_pause(unsigned int gpio, uint32_t event)
{
    is_running = !is_running;
    if (is_running) {
        current_beat = max_beat;
        current_ubeat = 0;
        start_timer();
    } else {
        stop_timer();
    }
}


/**
 * Handles cycling of the time signature when the time signature 
 * encoder is rotated
 * 
 * @param The GPIO pin number
 * @param The GPIO event type
 */
void isr_time_sig_encoder(unsigned int gpio, uint32_t event)
{
    if (gpio_get(TSIG_ENC1) == 1) { // "Forward"
        if (time_sig < TSIG_MAX - 1) {
            ++time_sig;
        } else {
            time_sig = 0;
        }
    } else { // Backward
        if (time_sig > 0) {
            --time_sig;
        } else {
            time_sig = TSIG_MAX - 1;
        }
    }
    max_beat = time_signatures[time_sig].max_ticks;
    
    // Tell screen to do an update
    mutex_enter_blocking(&mod_data.mutex_do_screen_update);
    mod_data.do_screen_update = true;
    mutex_exit(&mod_data.mutex_do_screen_update);
}


/**
 * Handle a button press on the squish pad
 */
TrellisCallback isr_pad_event(keyEvent evt)
{
    // On rising edge, send the update only if
    // the user pressed a valid beat for this
    // time signature
    if (evt.bit.EDGE == SEESAW_KEYPAD_EDGE_RISING &&
        evt.bit.NUM < max_beat) {
        beat_update_t msg = {
            .op = CHANGE_VELOC,
            .beat = evt.bit.NUM,
            .delta_veloc = 1 // Just increment the velocity
        };
        // Send the event to the other core
        // If the queue is full, ignore the data...
        queue_try_add(&mod_data.queue_button_event, &msg);
    }
        
    return 0; // Does something...
}


/**
 * Start the timeout for the clear grid operation. But do not yet
 * clear the grid.
 */
void isr_clear_pattern_start_timeout(unsigned int gpio, uint32_t event)
{
    if (gpio_get(CLEAR_BTN) == 0) {
        alarm_clear_grid_id = add_alarm_in_ms(
            CLEAR_GRID_TIMEOUT_MS,
            alarm_clear_pattern_callback,
            NULL,
            false
            );
    }
    else {
        // Cancel the timeout if the button was released during the timeout
        // 
        // Returns false if the alarm ID is invalid, so it should be
        // fine that this will be run after the button is released
        // (and thus after the alarm ID has expired)
        cancel_alarm(alarm_clear_grid_id);
    }
}


/**
 * Send a message to CORE 1 to reset all beat data on the current module
 * if the clear button has been held down for the full timeout period
 */
int64_t alarm_clear_pattern_callback(alarm_id_t id, void *user_data)
{
    // Make sure that the button is still held down.
    if (gpio_get(CLEAR_BTN) == 0) {
        beat_update_t msg = {
            .op = CLEAR_GRID,
            .beat = 0,
            .delta_veloc = 0
        };    
        queue_add_blocking(&mod_data.queue_button_event, &msg);
    }
    return 0; // Don't repeat timer
}


/**
 * Runs on CORE1 (the second core)
 * Handles sending data to modues and reading data
 * back from the modules.
 */
void module_data_controller(void)
{
    beat_update_t msg;
    uint32_t owner;
    ctlword_t _mods[connected_module_count];
    ctlword_t *mods = _mods;
    size_t i;
    
    while (true) {
        // See if the user pushed a button. If so, update
        // that beat's data
        while (queue_try_remove(&mod_data.queue_button_event, &msg)) {
            handle_beat_data_change(&msg);
        }
        
        // Try to read the module status change
        // It's OK if we can't for a few tries
        if (mutex_try_enter(&mod_data.mutex_has_mod_irq, &owner)) {
            if (queue_is_empty(&mod_data.queue_button_event)) {
                if (mod_data.has_mod_irq) {

                    // Get the selection status of all modules
                    serbus_read_cmd_all(mods);

                    // Go through the modules and find the first one
                    // which is selected
                    for (i = 0; i < connected_module_count && !mods[i].data.modsel; ++i) {
                        /* loop */
                    }
                    // Then force deselect all other modules
                    if (i < connected_module_count && mods[i].data.modsel) {
                        serbus_select_module(i);
                        // Signal that a module is selected
                        mod_data.is_mod_selected = true;
                        mod_data.selected_mod_index = i;
                        // Read in the selected module's data
                        get_module_beats();
                    }
                    else {
                        serbus_select_module(-1); // Deselect all
                        // Signal that no modules are selected
                        mod_data.is_mod_selected = false;
                        mod_data.selected_mod_index = 0;
                        clear_beats();
                    }
                    
                    mod_data.has_mod_irq = false;
                }
            }
            mutex_exit(&mod_data.mutex_has_mod_irq);
        }

    }
}


/**
 * Read out all beats from the module specified by selected_mod_index
 * and store them in the mod_data.beats array
 */
void get_module_beats(void)
{
    mutex_enter_blocking(&mod_data.mutex_beats);

    size_t i;
    ctlword_t res;
    for (i = 0; i < max_beat; ++i) {
        res.raw = 0;
        res.data.beat = i;
        res.data.rwb = true; // Read
        res.data.cs = true;
        serbus_read_cmd(mod_data.selected_mod_index, res, &res);
        mod_data.beats[i].veloc = res.data.veloc;
        mod_data.beats[i].ubeat = res.data.ubeat;
    }
    
    mutex_exit(&mod_data.mutex_beats);
}
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

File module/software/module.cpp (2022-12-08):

/**
 * MODULE CONTROLLER
 * 
 * Authors:
 * Zach Baldwin
 * Andy Regli
 * Mark Vaughn
 *
 */

// Uncomment to remove samples and enable fast compilation/upload
// #define FAST_COMP

#include <math.h>

#include "pico/stdlib.h"
#include "pico/util/queue.h"
#include "pico/multicore.h"
#include "hardware/adc.h"
#include "hardware/gpio.h"
#include "hardware/spi.h"

#ifdef FAST_COMP
uint16_t samples[][1]  = {{1}};
#define SAMPLE_LENGTH 1
#else
#include "samples.h"
#endif

#include "module.pio.h"
#include "serbus.h"
#include "module.h"

volatile bool is_selected;
volatile bool dac_loaded; // True following a DAC load event, false otherwise
volatile int current_beat;
volatile int playback_beat;
volatile size_t sample_index;
uint16_t variability; // The scaled reading from the DAC
volatile uint16_t variability_rand; // The random value to be used on the next sample

repeating_timer_t sample_timer;

volatile beat_data_t beats[16];

struct {
    uint sm;
    PIO pio;
    uint offs;
} intermodule_pio;

int main ()
{
    // Hardware init
    stdio_init_all();

    // Output Pins
    gpio_init(GPIO_DAC_LDACB);
    gpio_init(GPIO_DAC_CSB);
    gpio_set_dir(GPIO_DAC_LDACB, GPIO_OUT);
    gpio_set_dir(GPIO_DAC_CSB, GPIO_OUT);
    gpio_put(GPIO_DAC_LDACB, true);
    gpio_put(GPIO_DAC_CSB, true); // Active low, so disable DAC selection upon RESET
    gpio_set_function(GPIO_DAC_SCK, GPIO_FUNC_SPI);
    gpio_set_function(GPIO_DAC_SDAT, GPIO_FUNC_SPI);

    gpio_init(GPIO_SEL_LED);
    gpio_set_dir(GPIO_SEL_LED, GPIO_OUT);
    
    
    // Input pins
    gpio_init(GPIO_SEL_BTN);
    gpio_init(MOD_TEMPO_SYNC);
    gpio_set_dir(GPIO_SEL_BTN, GPIO_IN);
    gpio_set_dir(MOD_TEMPO_SYNC, GPIO_IN);

    // The "Hey, I've changed status" line
    gpio_init(MOD_STAT_IRQ);
    gpio_put(MOD_STAT_IRQ, 0);
    gpio_set_dir(MOD_STAT_IRQ, GPIO_IN);

    // Variability pot is an analog input
    adc_init();
    adc_gpio_init(GPIO_ADC2); // Setup pin input buffers
    adc_select_input(2); // Match ADC number
    
    // Init
    is_selected = false;
    variability = 0;
    variability_rand = 0;
    dac_loaded = true;
    current_beat = 0;
    playback_beat = 0;
    sample_index = SAMPLE_LENGTH;
    clear_beats();

    // Set up DAC SPI communication.
    // DAC is write-only
    spi_init(spi0, SPI_DAC_DATA_RATE_HZ);
    spi_set_format(
        spi0,
        16, // Number of bits, defined by DAC
        SPI_CPOL_1,
        SPI_CPHA_1,
        SPI_MSB_FIRST
        );

    // Init the PIO state machine which handles
    // intermodule communication
    // NOTE: If the PIO number is changed for this,
    // make sure to update the number for the IRQ handler
    // in the code that follows.
    intermodule_pio.pio = pio0;
    intermodule_pio.sm = pio_claim_unused_sm(intermodule_pio.pio, true);
    intermodule_pio.offs = pio_add_program(intermodule_pio.pio, &module_sio_program);
    module_sio_init(
        intermodule_pio.pio,
        intermodule_pio.sm,
        intermodule_pio.offs,
        GPIO_CBUS_SCK,
        GPIO_CBUS_DRDY,
        GPIO_CBUS_SDOUT,
        GPIO_CBUS_SDIN
        );

    
    // The PIO for the module uses an interrupt to tell
    // the main program that there is new data waiting to
    // be read from the intermodule communication bus.
    // We need to set up a handler for this event.
    // irq_set_exclusive_handler(PIO0_IRQ_0, isr_serbus);

    // With the handler for the PIO configured, we can
    // go ahead and enable the interrupt
    // irq_set_enabled(PIO0_IRQ_0, true);

    // Startup the second core to allow high-speed
    // response times to the intermodule communication bus.
    // This could be done on core 0 but since core 1 is free,
    // we can use it to (probably marginally) reduce
    // response delay.
    multicore_launch_core1(intermodule_command_handler);

    // Set up all the interrupt handlers for the GPIOs
    gpio_set_irq_enabled_with_callback(
        GPIO_SEL_BTN,
        GPIO_IRQ_EDGE_RISE,
        true, // (enable isr)
        &isr_gpio_handler
        );

    
    gpio_set_irq_enabled(
        MOD_TEMPO_SYNC,
        GPIO_IRQ_EDGE_FALL,
        true // (enable isr)
        );

    // Set up 44100 KHz sample clock
    // Again, ignoring the return value from this... Might need to fix in future
    add_repeating_timer_us(
        -1000000 / AUDIO_SAMPLE_RATE_HZ,
        isr_sample,
        NULL,
        &sample_timer
        );


    int angle;

    // For testing purposes, if the system boots with SELECT button held
    // down, output a 1KHz sine wave
    while (gpio_get(GPIO_SEL_BTN) == 1) {
        if (dac_loaded) {
            dac_loaded = false;
            ++angle;
            write_dac(0x8000+(int16_t)(32767.0*sin((double)angle*4*3.14159*(double)1000/(double)AUDIO_SAMPLE_RATE_HZ)));
        }
    }
    
    uint16_t m;
    int veloc;
    
    // Event loop
    while (1) {
        gpio_put(GPIO_SEL_LED, is_selected);
        
        variability = read_variability_pot();

        /**
         * Shift the next sample value into the DAC for playback
         * Note: This does not actually load the DAC!!!
         * This only fills up the shift register with the
         * next beat's sample data. The tempo sync ISR will
         * handle loading of the DAC.
         */
        if (dac_loaded) {
            dac_loaded = false;

            // Get the velocity for the given beat
            veloc = ((beats[playback_beat].veloc & 0x7) << VARIABILITY_STEPS_LOG)
                | (variability_rand & (VARIABILITY_STEPS - 1));

            if (beats[playback_beat].veloc && sample_index < SAMPLE_LENGTH) {
                ++sample_index;
                m = samples[veloc][sample_index] + 0x8000;
            } else {
                m = 0x8000; // Midscale
            }

            write_dac(m);
        }
    }
}


/**
 * Reset the sequencer grid
 */
void clear_beats(void)
{
    // 16 beats
    for (size_t i = 0; i < 16; ++i) {
        beats[i].ubeat = 0;
        beats[i].veloc = 0;
    }
}


/**
 * Read the analog value of the variability pot and return a numberically-
 * binned value corresponding to it.
 */
inline uint16_t read_variability_pot(void)
{
    // The ADC is only 12 bits, but we need 32 so the descitization of the
    // range does not overflow
    uint32_t val = adc_read();
    val *= VARIABILITY_STEPS;
    val /= (1<<12)-1;
    return val;
}


/**
 * Shift a value (m) into the DAC's SR but do not load it to the analog output
 * @param m The value to send to the dac
 */
inline void write_dac(uint16_t m)
{
    // Enable the DAC
    gpio_put(GPIO_DAC_CSB, false);

    // Send the new value
    spi_write16_blocking(
        spi0,
        &m,
        1
        );

    // Disable the DAC
    gpio_put(GPIO_DAC_CSB, true);

}
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

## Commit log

2022-09-14 Init dir structure; create kicad projects
    [module-hardware.kicad_pcb, module-hardware.kicad_sch, sequencer-hardware.kicad_pcb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]
2022-09-15 Add LDO & QSPI flash to module schematic
    [module-hardware.kicad_sch]
2022-09-18 Designed a rough audio summing bus
    [sequencer-hardware.kicad_sch]
2022-09-19 Add USB, XTAL, ADC headers, MCU bypass caps, reset
    [module-hardware.kicad_sch]
2022-09-19 Added master volume
    For next time: need to consider level shifting on the DAC output
    0-3.3V -> 0-12V?
    [sequencer-hardware.kicad_sch]
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2022-09-19 Start work on dsub pinout/connections
    [module-hardware.kicad_sch]
2022-09-21 Add module schematic TODO
    [module-hardware.kicad_sch]
2022-09-21 Reworked audio summing in main sequencer.
    Might still need to think about level shifting
    [sequencer-hardware.kicad_sch]
2022-09-21 Added analog mux to custom symbol library
    [module-hardware.kicad_sch]
2022-09-21 Isolated Analog & Digital GND
    Also added coupling caps to sequencer mixer
    [module-hardware.kicad_sch, sequencer-hardware.kicad_sch]
2022-09-21 Reworked audio routing to avoid MUX
    [module-hardware.kicad_sch]
2022-09-23 Move digital to separate sheet
    [digital.kicad_sch, module-hardware.kicad_sch]
2022-09-23 Add loopback routing mux; add digital signals to headers
    [digital.kicad_sch, module-hardware.kicad_pcb, module-hardware.kicad_sch]
2022-09-24 Added pull-down resistors to analog passthroughs
    [module-hardware.kicad_sch]
2022-09-25 Finished preliminary audio routing
    [sequencer-hardware.kicad_sch]
2022-09-25 Fixed a few weird wires
    [sequencer-hardware.kicad_sch]
2022-09-26 Add ADC vref, encoder & button headers
    [digital.kicad_sch, module-hardware.kicad_sch]
2022-09-26 Fix voltage rev supply (5V -> 3V3)
    [digital.kicad_sch, module-hardware.kicad_sch]
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2022-09-26 Finish footprint assignments; create cusom footprint lib
    [digital.kicad_sch, module-hardware.kicad_sch]
2022-09-26 Fix header footprints
    [digital.kicad_sch, module-hardware.kicad_sch]
2022-09-26 Begin layout process for module
    [digital.kicad_sch, module-hardware.kicad_pcb, module-hardware.kicad_sch]
2022-09-27 Complete board layout component placement & outline approx
    [digital.kicad_sch, module-hardware.kicad_pcb, module-hardware.kicad_sch]
2022-09-27 Begin digital side routing
    [digital.kicad_sch, module-hardware.kicad_pcb, module-hardware.kicad_sch]
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2022-09-28 transferred digital system to sequencer schematic
    [digital.kicad_sch, sequencer-hardware.kicad_sch]
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2022-09-28 Reorder RP2040 GPIO lines for improved routability
    [digital.kicad_sch, module-hardware.kicad_pcb, module-hardware.kicad_sch]
2022-09-28 Route global SPI bus
    [module-hardware.kicad_pcb]
2022-09-30 Created slidepot daughter board
    [slidepot.kicad_pcb, slidepot.kicad_sch]
2022-09-30 Replace slidepot with slidepot daughterboard
    [module-hardware.kicad_pcb, module-hardware.kicad_sch]
2022-09-30 Correct direction of input/output connectors for digital signals
    [module-hardware.kicad_pcb, module-hardware.kicad_sch, slidepot.kicad_pcb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]
2022-10-01 Module Analog preliminaty routing complete
    [digital.kicad_sch, module-hardware.kicad_pcb, module-hardware.kicad_sch]
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2022-10-03 Export STEP of module
    [module-hardware.step]
2022-10-03 Finish Module PCB routing (DAC SPI lines)
    [module-hardware.kicad_pcb]
2022-10-03 Fix +5V plane, cleanup silkscreen
    [module-hardware.kicad_pcb]
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2022-10-07 John Gibbons 30Khz LP & DAC analog power jumper
    [digital.kicad_sch, module-hardware.kicad_pcb, module-hardware.kicad_sch]
2022-10-07 Generate STEP of Module
    [module-hardware.step]
2022-10-07 Implement changes to sequencer recommended by John
    [digital.kicad_sch, sequencer-hardware.kicad_sch]
2022-10-10 Denote start ground point
    [sequencer-hardware.kicad_sch]
2022-10-10 Add pull down button resistor option
    [digital.kicad_sch, module-hardware.kicad_pcb, module-hardware.kicad_sch]
2022-10-11 Add M3 mounting holes; add HW/Layout REV IDs
    [module-hardware.kicad_pcb, module-hardware.kicad_sch]
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2022-10-11 Modify main enclosure to better fit connectors
    [MainEnclosure.SLDPRT]
2022-10-12 Fix scan chain pin labeling on input connector
    [digital.kicad_sch, sequencer-hardware.kicad_sch]
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2022-10-14 Move Module CAD into cad folder
    [BasePlate.SLDPRT, EnclosureAssembly.SLDASM, MainEnclosure.SLDPRT]
2022-10-15 Finalized PCB soldermask labeling for Module
    [module-hardware.kicad_pcb]
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2022-10-15 Add optional pulldown resistors to buttons
    [sequencer-hardware.kicad_sch]
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2022-10-15 Add filter sections to encoders
    [digital.kicad_sch, sequencer-hardware.kicad_sch]
2022-10-17 Disconnect GNDD from GNDA to prevent routing confusion
    [digital.kicad_sch, sequencer-hardware.kicad_pcb, sequencer-hardware.kicad_sch]
2022-10-17 Do a lot of random stuff
    [digital.kicad_sch, sequencer-hardware.kicad_pcb, sequencer-hardware.kicad_sch]
2022-10-18 Add project copy of RP2040 footprint
    [module-hardware.kicad_pcb, sequencer-hardware.kicad_pcb]
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2022-10-21 Split slidepot into 45 and 60 mm boards
    [slidepot.kicad_pcb, slidepot.kicad_sch]
2022-10-21 Add common mode choke
    [sequencer-hardware.kicad_sch]
2022-10-21 Rename slidepot 45 and 60
    [slidepot-45.kicad_pcb, slidepot-45.kicad_sch, slidepot-60.kicad_pcb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]
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2022-10-21 Update sequencer-hardware.kicad_sch
    footprints updated
    [sequencer-hardware.kicad_sch]
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2022-10-22 add mounting holes, arrange all parts
    [sequencer-hardware.kicad_pcb, sequencer-hardware.kicad_sch]
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2022-10-26 Add final mounting hole and generate STEP file
    [seqPCB.step, sequencer-hardware.kicad_pcb, sequencer-hardware.kicad_sch]
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2022-10-30 Fix OPA power polarity; Add Reg protection diodes; Cleanup silk
    [sequencer-hardware.kicad_pcb, sequencer-hardware.kicad_sch]
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2022-11-09 modify module enclosure, fix 3d model references
    [54-00133.STEP, BasePlate.SLDPRT, EnclosureAssembly.SLDASM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]
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2022-11-15 Resolve lots of syntax errors in Wire.h; now there's linking errors...
    [Arduino.h, Wire.cpp, Wire.h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]
2022-11-15 Add I2c Init; Fix minor errors inWire; IT WORKS!!! (Mostly, there's one Neopixel stuck on)
    [Wire.cpp, sequencer.cpp]
2022-11-15 Fix 'stuck pixel'; Increase Request Timeout
    [Wire.cpp, Wire.h, sequencer.cpp]
2022-11-16 OLED displays splash (Fix SSD1306 libs)
    [Arduino.h]
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2022-11-17 Route button debounce passives; bump HW rev to 1.1
    [sequencer-hardware.kicad_pcb]
2022-11-17 Route button debounce passives; bump HW rev to 1.1 (repeat)
    [digital.kicad_sch, sequencer-hardware.kicad_pcb, sequencer-hardware.kicad_sch]
2022-11-17 Add EXTRA1, btn debounce passives; Bump HW rev to 1.1
    [digital.kicad_sch, module-hardware.kicad_pcb, module-hardware.kicad_sch]
2022-11-17 Create short 45mm slidepot
    [PTA4543.stp, slidepot-45s.kicad_pcb, slidepot-45s.kicad_sch]
2022-11-18 Bump I2C frequency to 400kHz; correct play/pause timer operation
    [Wire.h, sequencer.cpp, sequencer.h]
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2022-12-03 RX PIO FIFO recieves correct data!
    [sequencer.cpp]
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2022-12-04 Fix connected module count function
    [sequencer.cpp]
2022-12-04 FIX: DRDY now goes high prior to SCK
    [sequencer.cpp]
2022-12-04 Fix module count function
    [sequencer.cpp]
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2022-12-05 Remove 'sample' beat field; Velocity playback fix Also: * It plays noises! (Drum samples, to be precise!!!)
    [module.cpp, sequencer.cpp]
2022-12-06 Fix intermodule bus (bidirectional comm now working\!)
    [module.cpp]
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2022-12-07 Fix path of CAD rendering
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2022-12-08 Fix 1kHz debug rate
    [module.cpp]
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
